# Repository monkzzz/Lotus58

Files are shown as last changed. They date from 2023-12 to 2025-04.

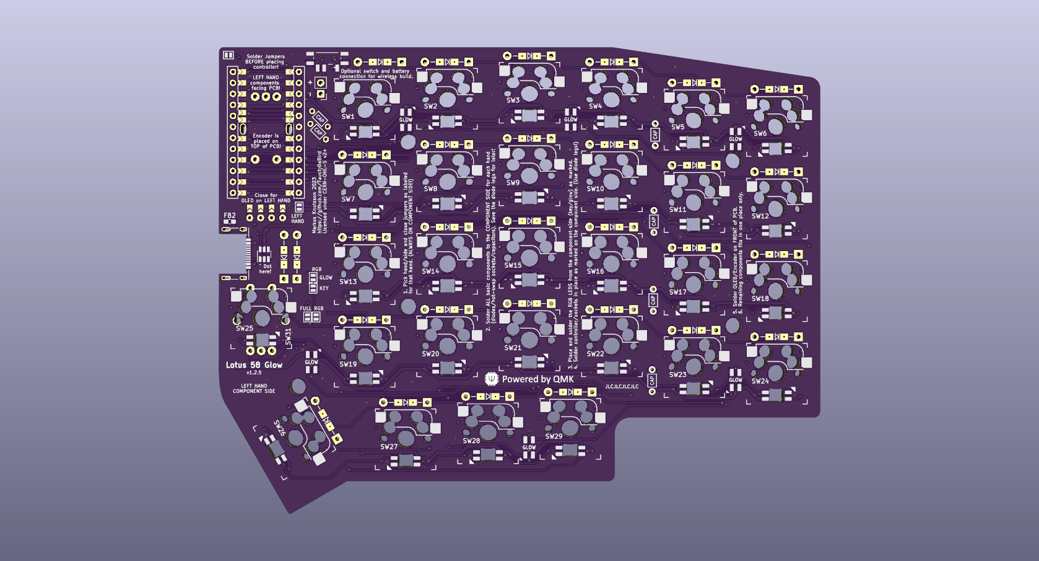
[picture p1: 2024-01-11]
images/Lotus58_Glow_130.png

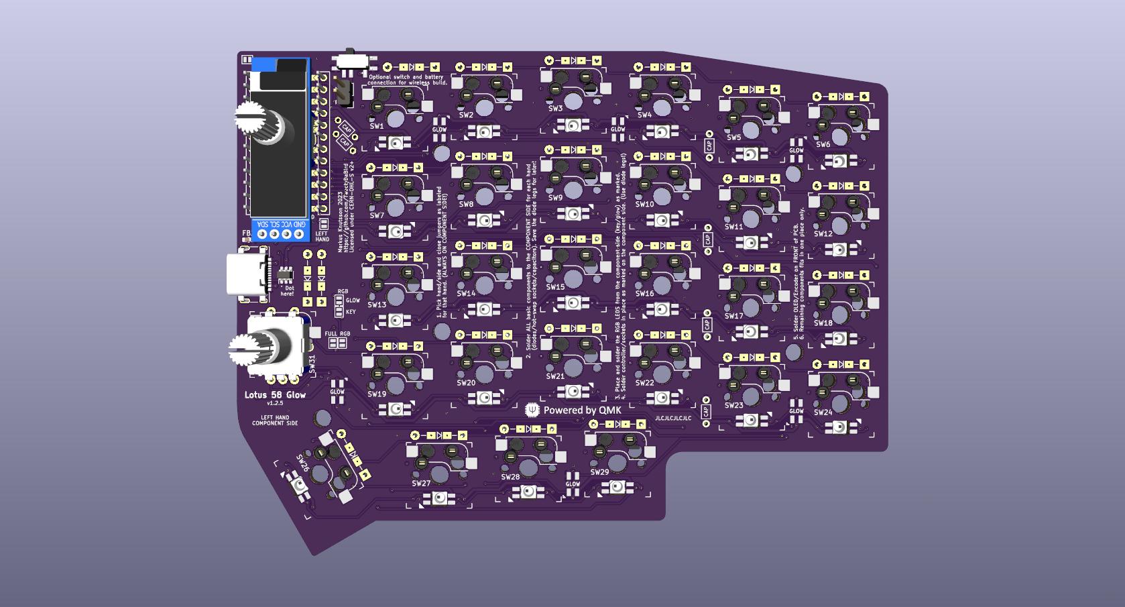
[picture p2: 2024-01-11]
images/Lotus58_Glow_130_LH_comp.jpg

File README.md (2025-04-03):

### Notice! Project files in the development branches are NOT intended for public use in production of PCB's, may or may not be tested and may change or be removed without notice! 
If you order PCB's from these, YOU have the sole responsibility for how these turn out!!! 

**Please use the Gerber files for producing PCB's, found under the header 'Releases' instead (Look here >>).** 

Also please note the difference between a 'Pre-release' (partially/fully untested, basically what I order a prototype PCB from to test) and a full actual 'Release' which is fully tested, built and ready to be used to produce PCB's.

# Lotus 58 Glow - Classic
#### Lotus 58 Classic is the wired designs of the Lotus keyboard. Wireless with BLE and 2.4Ghz dongled wireless reside in other repositories.

Starting with simple tweaks to the Lily58 Glow before ordering a set of PCB's it quickly spiraled out of control, and I ended up with what wasn't quite a Lily58 anymore, and although very similar in layout, it is no longer compatible with plate and case design. 

Because of this, it was renamed Lotus58, referencing another flower much like the lily in the name Lily58.

Lotus 58 Glow
(photo from reddit by u/bduzik)

## General Specifications

- Layout very similar to the original Lily58 family
- Per key RGB and RGB underglow
- Kaihl Hot-swap sockets for MX compatible switches
- Can be used as a standalone Gamepad for either hand
- Optional 0.91" OLED Screens and rotary encoders (one each per side)
- All components through-hole and easily soldered for beginners (SMD option for diodes)
- Designed with a sandwich-style plate/case as part of the design

## Layout variations

- Optional plate layout with OLED screen (Encoder can be placed on upper thumb key position)
- Optional plate layout with rotary encoder (Removes OLED screen for that side)  
- Optional plate layout with no hole for OLED or upper encoder (Encoder can be placed on upper thumb key position)

Layout variations Layout Variations

## 3D-printed Cases
**There are a couple of 'official' commissioned designs for 3D printed cases for the Lotus 58 Glow, available in a separate Git [here](https://github.com/TweetyDaBird/Lotus-Cases).** 

And you can find several more made by users using Google, and/or by joining the Discord channel and chatting to the builders/designers and users.

## Things to note when ordering PCB's
### Finding the Gerber files
If you are not aiming at modifying things, don't look for the gerber files in the folders, pretty please!</BR>
And please don't open yet another issue about it! </BR>
The gerber files are where they belong, zipped up in releases, look under that header for the version you want.

### Tips & Tricks
- Most PCB manufacturers have a MOQ of 5 PCB's, meaning you end up with 2½ keyboards when finished.
- The recommended PCB thickness is 1.6 mm, both for the main PCB and plates to allow the keyswitches to grip the plate and lock in place securely.

If ordering from [JLCPCB](https://www.jlcpcb.com) the plate Gerber files include a reference putting the added serial etc on a breakaway part for a clean look with minimal cost, if using another manufacturer it's possible they have additional fee's for removing the extra text, or you should consider plotting the Gerber files yourself with the correct reference for your manufacturer. Otherwise use the standard settings from JLPCB.

## Build guide
**Some basic build instructions are in the [WIKI](https://github.com/TweetyDaBird/Lotus-58-Classic/wiki), and I really try to keep these updated.** But please keep in mind that whenever these instructions conflict with information on the PCB silkscreen, the silkscreen is and always will be the correct source of information! It's always updated with the version, and the most current information for the PCB version in question. 

**The intent has always been that the keyboard should be able to be fully built with some very basic soldering skills and the instructions on the silkscreen.**

### Discord for further build help and discussions!

<a href="https://discord.gg/G6QzcJQUnm">Discuss on Discord</a>

## Buy a kit!
I sell complete kits, making it easy to build your keyboard, and it also supports prototypes for new wacky ones. 



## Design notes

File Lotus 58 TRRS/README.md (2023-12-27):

# Lotus 58 Glow

Starting with simple tweaks to the Lily58 Glow before ordering a set of PCB's it quickly spiraled out of control, and I ended up with what wasn't quite a Lily58 anymore, and although very similar in layout, it is no longer compatible with plate and case design. 

Because of this, it was renamed Lotus58, referencing another flower much like the lily in the name Lily58.

Lotus 58 Glow
(photo from reddit by u/bduzik)

## TRRS link version - Lotus 58 Classic

This is the original branch of the Lotus 58 Glow design, using the TRRS link. A lot of features have been added along the way for the newer versions.

## General Specifications

- Layout very similar to the original Lily58 family
- Per key RGB and RGB underglow
- Kaihl Hot-swap sockets for MX compatible switches
- Can be used as a standalone Gamepad for either hand
- Optional 0.91" OLED Screens and rotary encoders (one each per side)
- All components through-hole and easily soldered for beginners (SMD option for diodes)
- Designed with a sandwich-style plate/case as part of the design

## Layout variations

- Optional plate layout with OLED screen (Encoder can be placed on upper thumb key position)
- Optional plate layout with rotary encoder (Removes OLED screen for that side)  
- Optional plate layout with no hole for OLED or upper encoder (Encoder can be placed on upper thumb key position)

Layout variations Layout Variations

## Things to note when ordering PCB's
### Finding the Gerber files
If you are not aiming at modifying things, don't look for the gerber files in the folders, pretty please!</BR>
And please don't open yet another issue about it! </BR>
The gerber files are where they belong, zipped up in releases, look under that header for the version you want.

### Tips & Tricks
- Most PCB manufacturers have a MOQ of 5 PCB's, meaning you end up with 2½ keyboards when finished.
- The recommended PCB thickness is 1.6 mm, both for the main PCB and plates to allow the keyswitches to grip the plate and lock in place securely.

If ordering from [JLCPCB](https://www.jlcpcb.com) the plate Gerber files include a reference putting the added serial etc on a breakaway part for a clean look with minimal cost, if using another manufacturer it's possible they have additional fee's for removing the extra text, or you should consider plotting the Gerber files yourself with the correct reference for your manufacturer. Otherwise use the standard settings from JLPCB.

## Buy a kit!
I sell complete kits, making it easy to build your keyboard, and it also supports prototypes for new wacky ones. 



## Discord for build help and discussions!

<a href="https://discord.gg/G6QzcJQUnm">Discuss on Discord</a>

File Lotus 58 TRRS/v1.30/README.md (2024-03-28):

# Lotus 58 v1.28

Starting with simple tweaks to the Lily58 Glow before ordering a set of PCB's it quickly spiraled out of control, and I ended up with what wasn't quite a Lily58 anymore, and although very similar in layout, it is no longer compatible with plate and case design. 

Because of this, it was renamed Lotus58, referencing another flower much like the lily in the name Lily58.

# Lotus 58 Glow

Lotus 58 Glow
(photo from reddit by u/bduzik)

Fully backwards compatible physically identical outline for plates and identical firmware. Updates required to 3D cases for the reset/power switch.

# Parts needed

| Name of part | Qty. | Optional | Remarks | Aliexpress |
| --- | ---- | --- | --- | --- |
| PCB | 2 | X | 1,6 mm thick | X |
| Top plate | 2 | X | Optional layouts for OLED or encoder in top position. | X |
| Bottom plate | 2 | X | X | X |
| Kailh hotswap socket | 56-58 | X | Qty. depends on layout. | [link](https://www.aliexpress.com/item/-/4001051840976.html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) |
| Diodes 1N4841 (TH) or 1N4148W (SMD) | 56-58 | X | Qty. depends on layout. TH recommended for beginners. | [link(TH)](https://www.aliexpress.com/item/HOT-SELL-100-PCS-1N4148-DO-35-IN4148-Silicon-Switching-Diode-FREE-SHIPPMENT/32660088529.html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) or [link(SMD)](https://www.aliexpress.ru/item/-/1005002059571417.html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) |
| Capacitors 100 nF | 0-4 | ✔ | Qty. depends on layout. 2 needed for each encoder installed. | [link](https://www.aliexpress.com/item/-/32971478818.html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) |
| Resistor 4.7 kOhm | 0-4 | ✔ | Qty. depends on layout. 2 needed for each OLED installed. | [link](https://www.aliexpress.com/item/-/32847047012.html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) |
| 0.91" OLED Display | 0-2 | ✔ | Qty. depends on layout. | [link](https://www.aliexpress.com/item/-/4001028384269.html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) |
| TRRS jack PJ-320A | 2 | X | X | [link](https://www.aliexpress.com/item/-/4000114275750.html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) |
| M2 * 12 mm standoff | 10 | X | Rounded, max 3.7 mm in diameter | [link](https://www.aliexpress.com/item/-/32863484622.html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) |
| M2 * 4 mm screw | 20 | X | 4-8 mm length fits, low profile hex head recommended | [link](https://www.aliexpress.com/item/-/32966917947.html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) |
| TRRS cable | 1 | X | Needs to be 4 poles, more common 3 poles cable creates a shortcircuit | [link](https://www.aliexpress.com/item/32905903526.html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,searchweb201602_,searchweb201603_) |
| Silicon pads | 10 | X | X | [link](https://www.aliexpress.com/item/-/32912066603.html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) |
| Pro Micro | 2 | X | Can be built with various ProMicro clones as well as Elite C (Or nice!nano for a wireless keyboard) | [link](https://www.aliexpress.com/item/-/32849563958.html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) |
| MillMax low profile sockets | 1 | ✔ | Purchased as 1x64 pin and split | [link](https://eu.mouser.com/ProductDetail/575-641503)|
| Rotary Encoder | 0-2 | ✔ | Qty. depends on layout. | [link](https://www.aliexpress.com/item/10000056483250.html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,searchweb201602_,searchweb201603_) |
| Rotary Encoder Knob | 0-2 | ✔ | One needed for each encoder. Clearance for max 24 mm diameter, pick halfshaft or spline according to encoder choice.  | [link](https://www.aliexpress.com/item/10000056483250.html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,searchweb201602_,searchweb201603_) |
| SK6803/SK6805/SK6812 mini-E (3535) | 12/58 (70) | ✔ | Qty. depends on layout and if used as per-key or underglow (or both). Mini E are winged for easier soldering. | [link](https://www.aliexpress.com/item/4000475685852.html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,searchweb201602_,searchweb201603_) |
| SRV05-4	ESD | 0-2 | ✔ | Optional but recommended for ESD protection. | [link](https://www.lcsc.com/product-detail/Electrostatic-and-Surge-Protection-TVS-ESD_TECH-PUBLIC-SRV05-4_C558418.html)|
| MSK12C02 Slide switch | 0-2 | ✔ | Optional RGB select or Power switch | [link](https://www.lcsc.com/product-detail/Slide-Switches_SHOU-HAN-MSK12C02_C431540.html)|

## Things to note when ordering PCB's
### Finding the Gerber files
If you are not aiming at modifying things, don't look for the gerber files in the folders, pretty please!</BR>
And please don't open yet another issue about it! </BR>
The gerber files are where they belong, zipped up in releases, look under that header for the version you want.

### Tips & Tricks
- Most PCB manufacturers have a MOQ of 5 PCB's, meaning you end up with 2½ keyboards when finished.
- The recommended PCB thickness is 1.6 mm, both for the main PCB and plates to allow the keyswitches to grip the plate and lock in place securely.

If ordering from [JLPCB](https://www.jlpcb.com) the plate Gerber files include a reference putting the added serial etc on a breakaway part for a clean look with minimal cost, if using another manufacturer it's possible they have additional fee's for removing the extra text, or you should consider plotting the Gerber files yourself with the correct reference for your manufacturer. Otherwise use the standard settings from JLPCB.

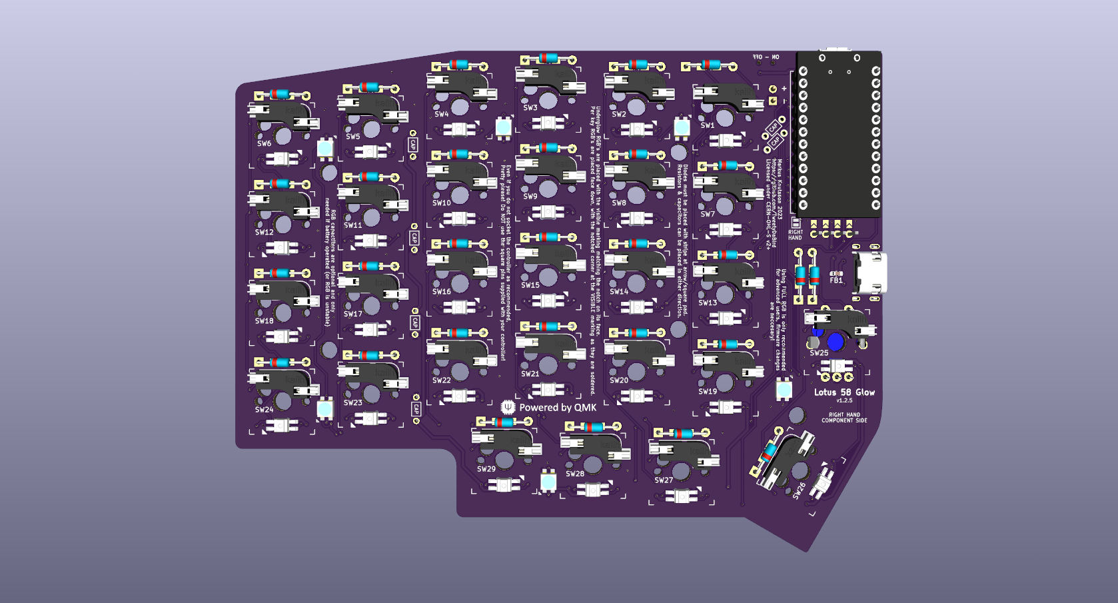
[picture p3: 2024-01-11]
images/Lotus58_Glow_130_RH_comp.png

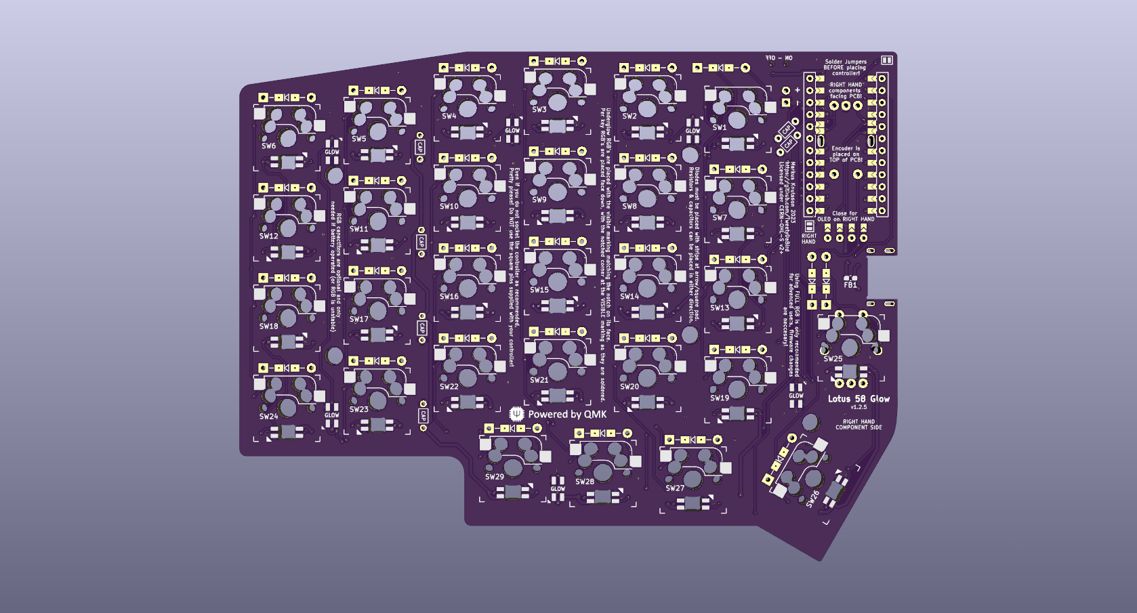
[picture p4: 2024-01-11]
images/Lotus58_Glow_130_RH.png

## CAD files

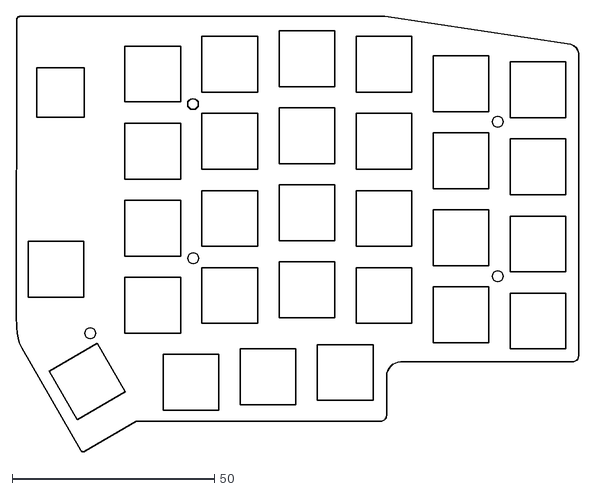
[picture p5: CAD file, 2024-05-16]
Lotus Plate/DXF/Laser_Cut_Top_Plate_ENC.dxf
139.1 x 107.7

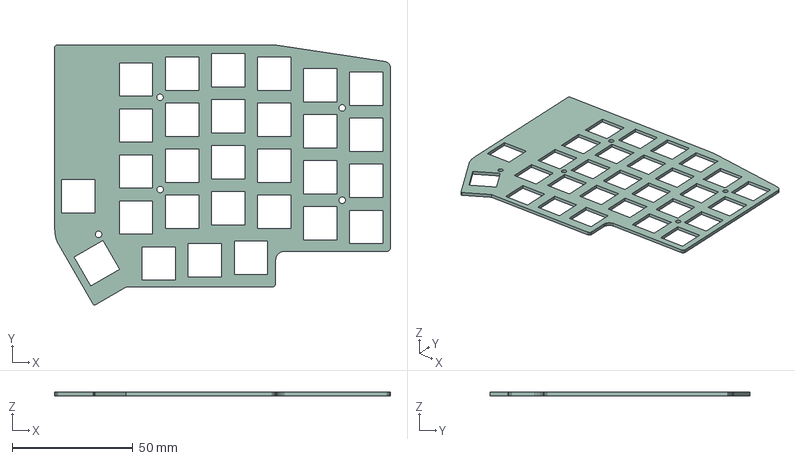
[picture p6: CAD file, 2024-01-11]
Lotus Plate/Step file/FR4_Top_Plate_BLANK.step
139.1 x 107.7 x 1.60 mm

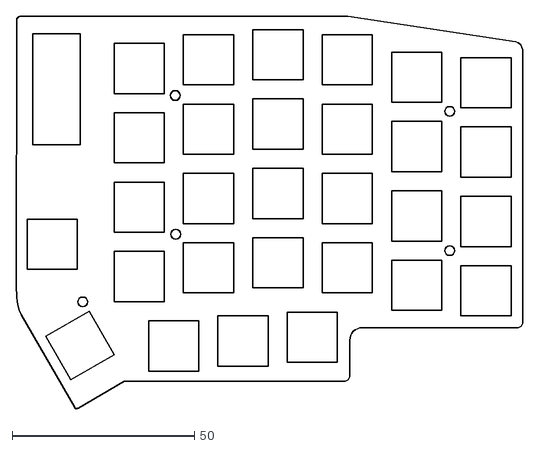
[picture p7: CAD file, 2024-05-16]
Lotus Plate/DXF/Laser_Cut_Top_Plate_OLED.dxf
139.1 x 107.7

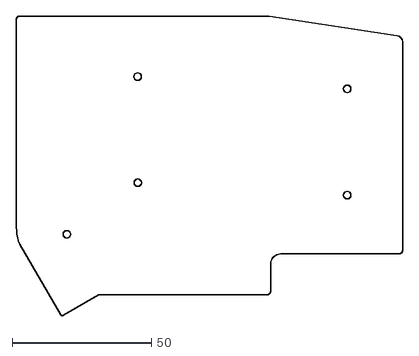
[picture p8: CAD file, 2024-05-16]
Lotus Plate/DXF/Laser_Cut_Bottom_Plate.dxf
139.1 x 107.7

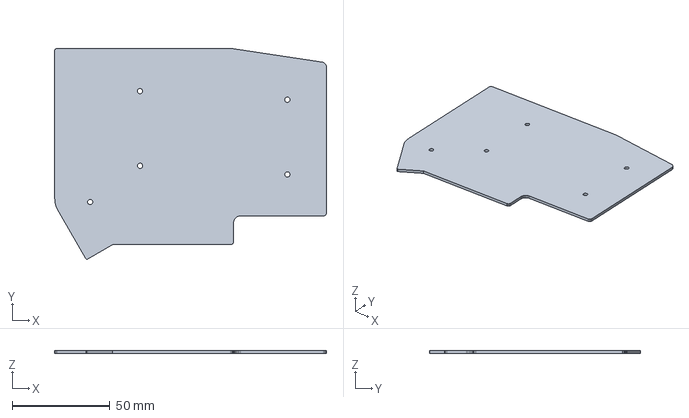
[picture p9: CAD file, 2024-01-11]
Lotus Plate/Step file/FR4_Bottom_Plate.step
139.1 x 107.7 x 1.60 mm

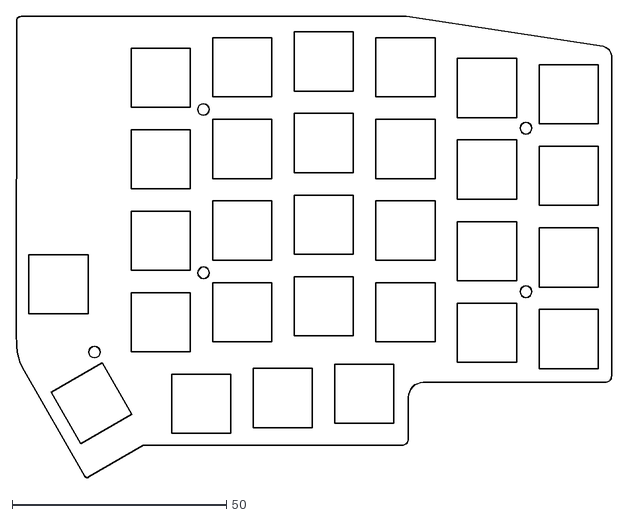
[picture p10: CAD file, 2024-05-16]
Lotus Plate/DXF/Laser_Cut_Top_Plate_Blank.dxf
139.1 x 107.7

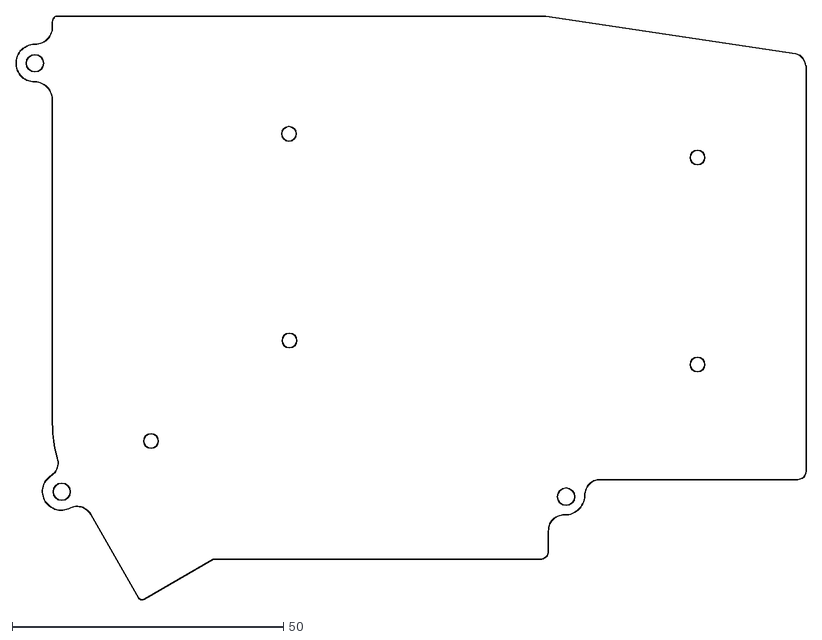
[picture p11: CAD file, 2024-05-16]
Lotus Plate/DXF/Laser_Cut_Bottom_Plate_TENT.dxf
145.7 x 107.7

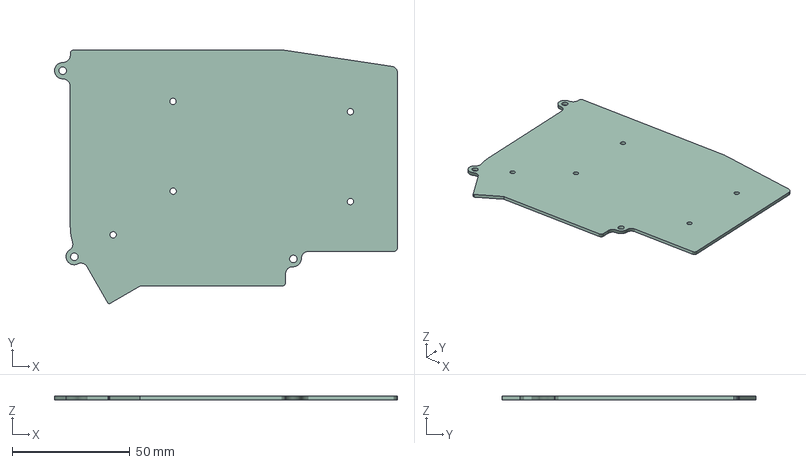
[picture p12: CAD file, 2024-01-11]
Lotus Plate/Step file/FR4_Bottom_Plate_TENT.step
145.7 x 107.7 x 1.60 mm

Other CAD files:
Lotus Plate/Step file/FR4_Top_Plate_OLED.step
Lotus Plate/Step file/FR4_Top_Plate_ENC.step

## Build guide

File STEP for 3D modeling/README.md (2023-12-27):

### STEP files used for 3D modeling cases etc.
All relevant components are modeled and present on both sides of the PCB, as they are not always 100% symmetrical (placement depends on traces etc). Keep in mind that the modeling should as standard use the component placed on the bottom side of the PCB for each respective hand.

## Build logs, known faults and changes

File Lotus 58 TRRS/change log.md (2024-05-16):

Change Log Lotus 58 Glow TRRS/Classic

- v1.00 - Initial release
   - This verison unfortunately had various RGB issues. Used through hole mounted SK6812 mini RGB's for both per-key and glow.
- v1.11 - Intermediary release
  - RGB issues fixed, improved silkscreen for easier building.
- v1.23 - Second release
  - Greatly improved design, per-key moved to SK6812 mini-e winged RGB, and glow remains as surface mounted SK6812 mini.
  - Added support for battery connector and power switch for wireless builds.
- v1.24 - Intermediary release
   - Added Silkscreen build instructions
  - Added TRRS ESD protection
  - Removed i2c resistors
  - Repositioned reset for easier access
  - Minor cleanup of routing and silkscreen
- v1.26 - Third Release
  - Brings TRRS variant to feature parity with USB C variant by moving ALL RGB to SK6812 mini-e.
  - All RGB can be soldered, and either glow or key can be selected to be active (drawing power)
  - Switch positions are the same as USB-C so reset and power switch can now be on both sides of PCB (easier 3D printing)
  - Better footprints, so easier to solder.
  - Since the TRRS version already have a power switch, the RGB is an internal switch, placed where you need to disassemble, alternatively hard soldered jumpers.
- v1.27 - Intermediary release
  - Improved Silkscreen/build instructions on PCB
- v1.28 - Fourth release
  - Possible to select the function of the external slide switch, setting it as a power switch for wireless builds, or to select RGB for a wired build

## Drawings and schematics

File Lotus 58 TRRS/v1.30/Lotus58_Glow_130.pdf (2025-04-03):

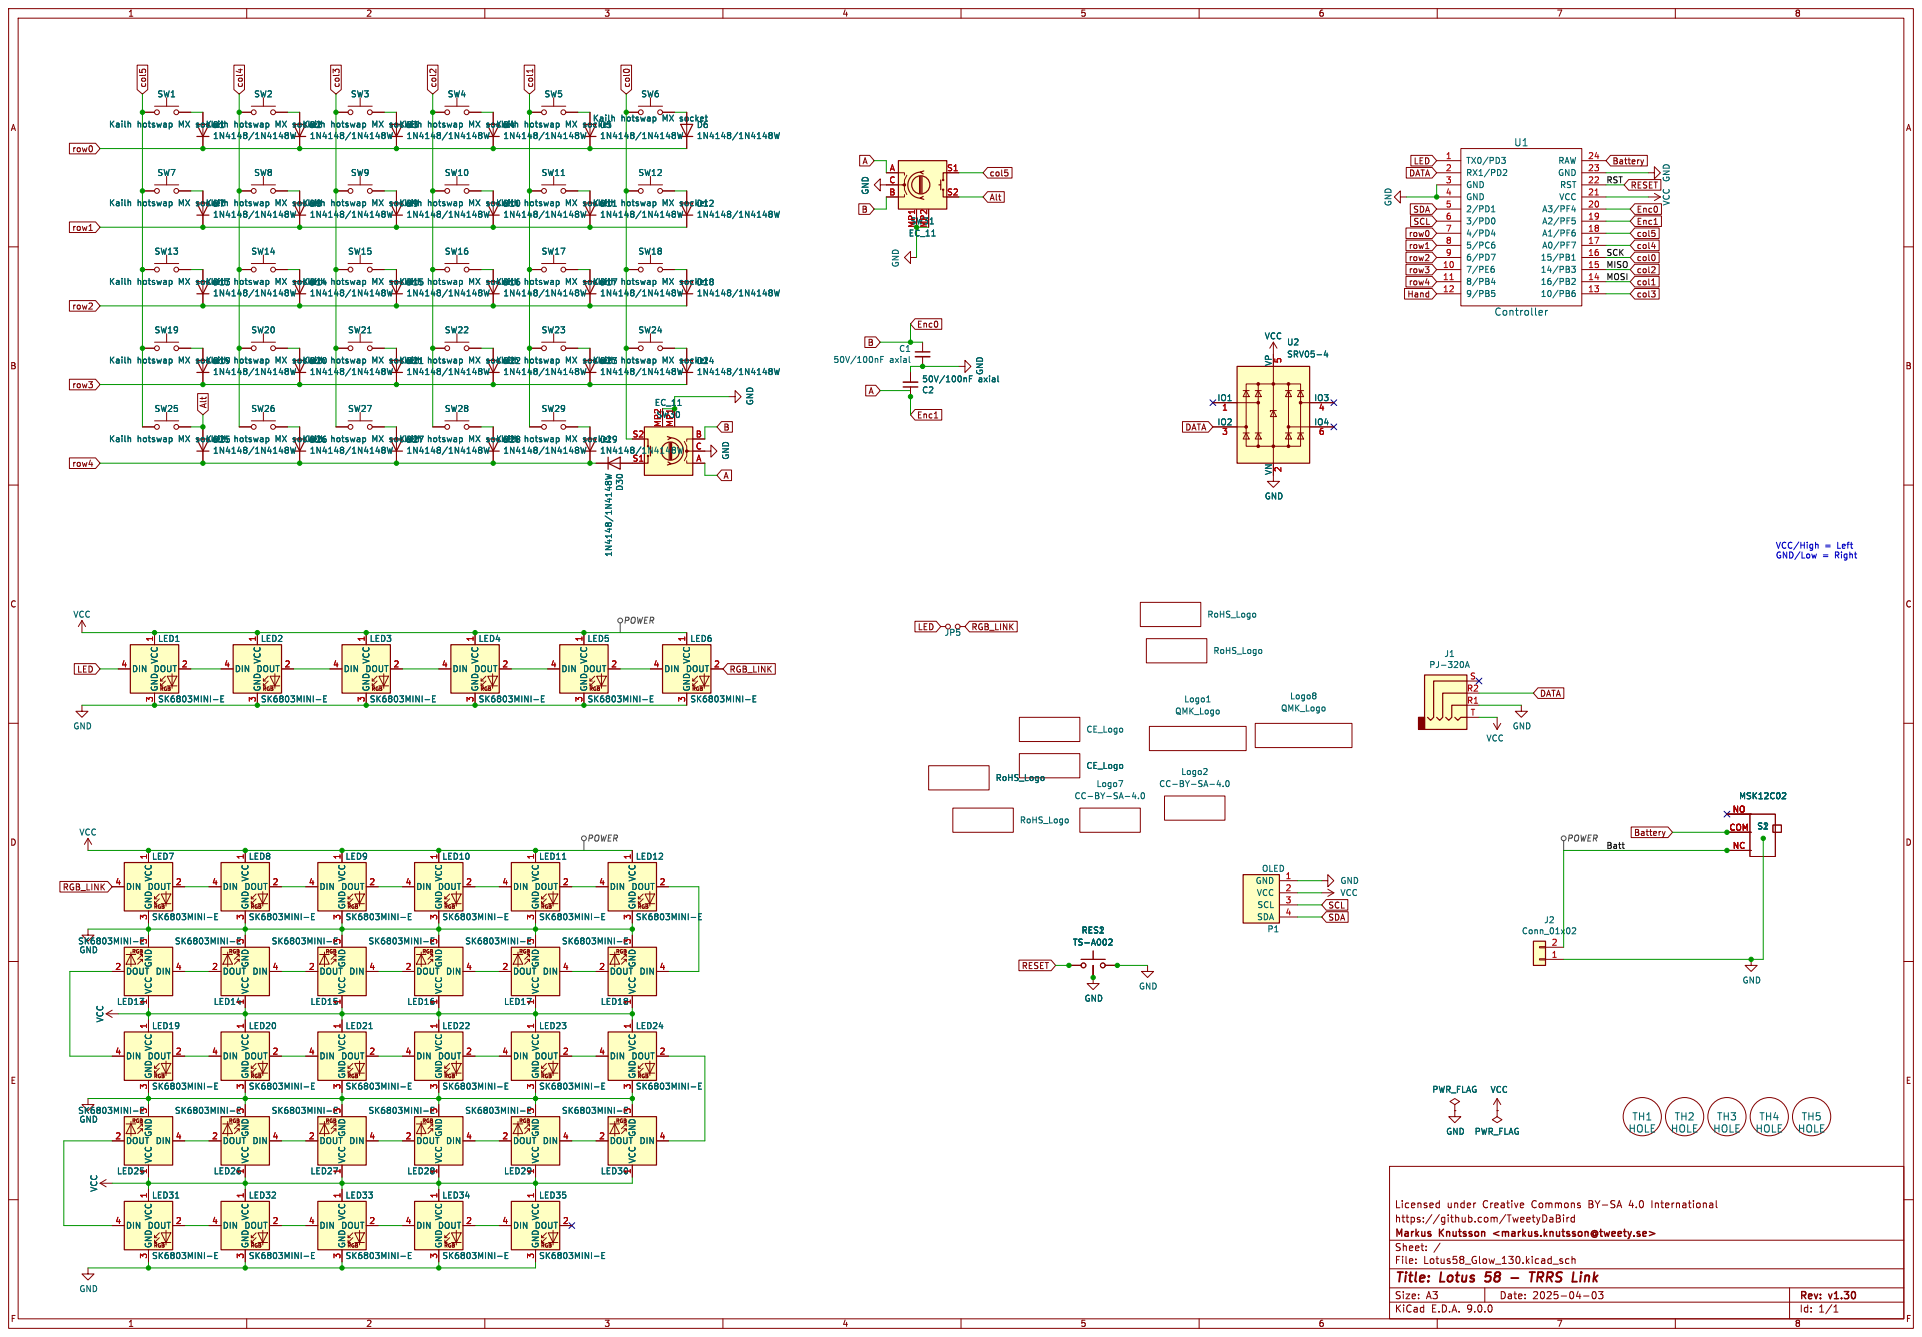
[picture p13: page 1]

SW2 Kailh hotswap MX socket D26

SW1 Kailh hotswap MX socket

SW3 Kailh D2 hotswap MX socket 1N4148/1N4148W

SW4 Kailh hotswap MX socket SW9 Kailh D8 hotswap MX socket 1N4148/1N4148W

SW4 Kailh hotswap MX socket

SW5 Kailh hotswap MX socket

SW6 Kailh hotswap MX socket SW12 Kailh hotswap MX socket D5

SW8 Kailh D7 hotswap MX socket 1N4148/1N4148W

SW9 Kailh D8 hotswap MX socket 1N4148/1N4148W

SW10 Kailh hotswap MX socket

SW10 Kailh D9 hotswap MX socket 1N4148/1N4148W

SW11 Kailh hotswap MX socket SW17 Kailh D16 hotswap MX socket 1N4148/1N4148W

SW18 Kailh hotswap MX socket D11

SW15 Kailh hotswap MX socket SW21 Kailh hotswap MX socket SW26 Kailh D25 hotswap MX socket 1N4148/1N4148W

SW16 Kailh hotswap MX socket

SW16 Kailh hotswap MX socket SW22 Kailh hotswap MX socket D15

SW20 Kailh hotswap MX socket D13

SW22 Kailh hotswap MX socket D15

SW24 Kailh hotswap MX socket D17

SW25 Kailh hotswap MX socket SW19 Kailh hotswap MX socket D19
SW25 Kailh hotswap MX socket VCC

VCC GND GND GND

https://github.com/TweetyDaBird

Id: 1/1 Title: Lotus 58 - TRRS Link

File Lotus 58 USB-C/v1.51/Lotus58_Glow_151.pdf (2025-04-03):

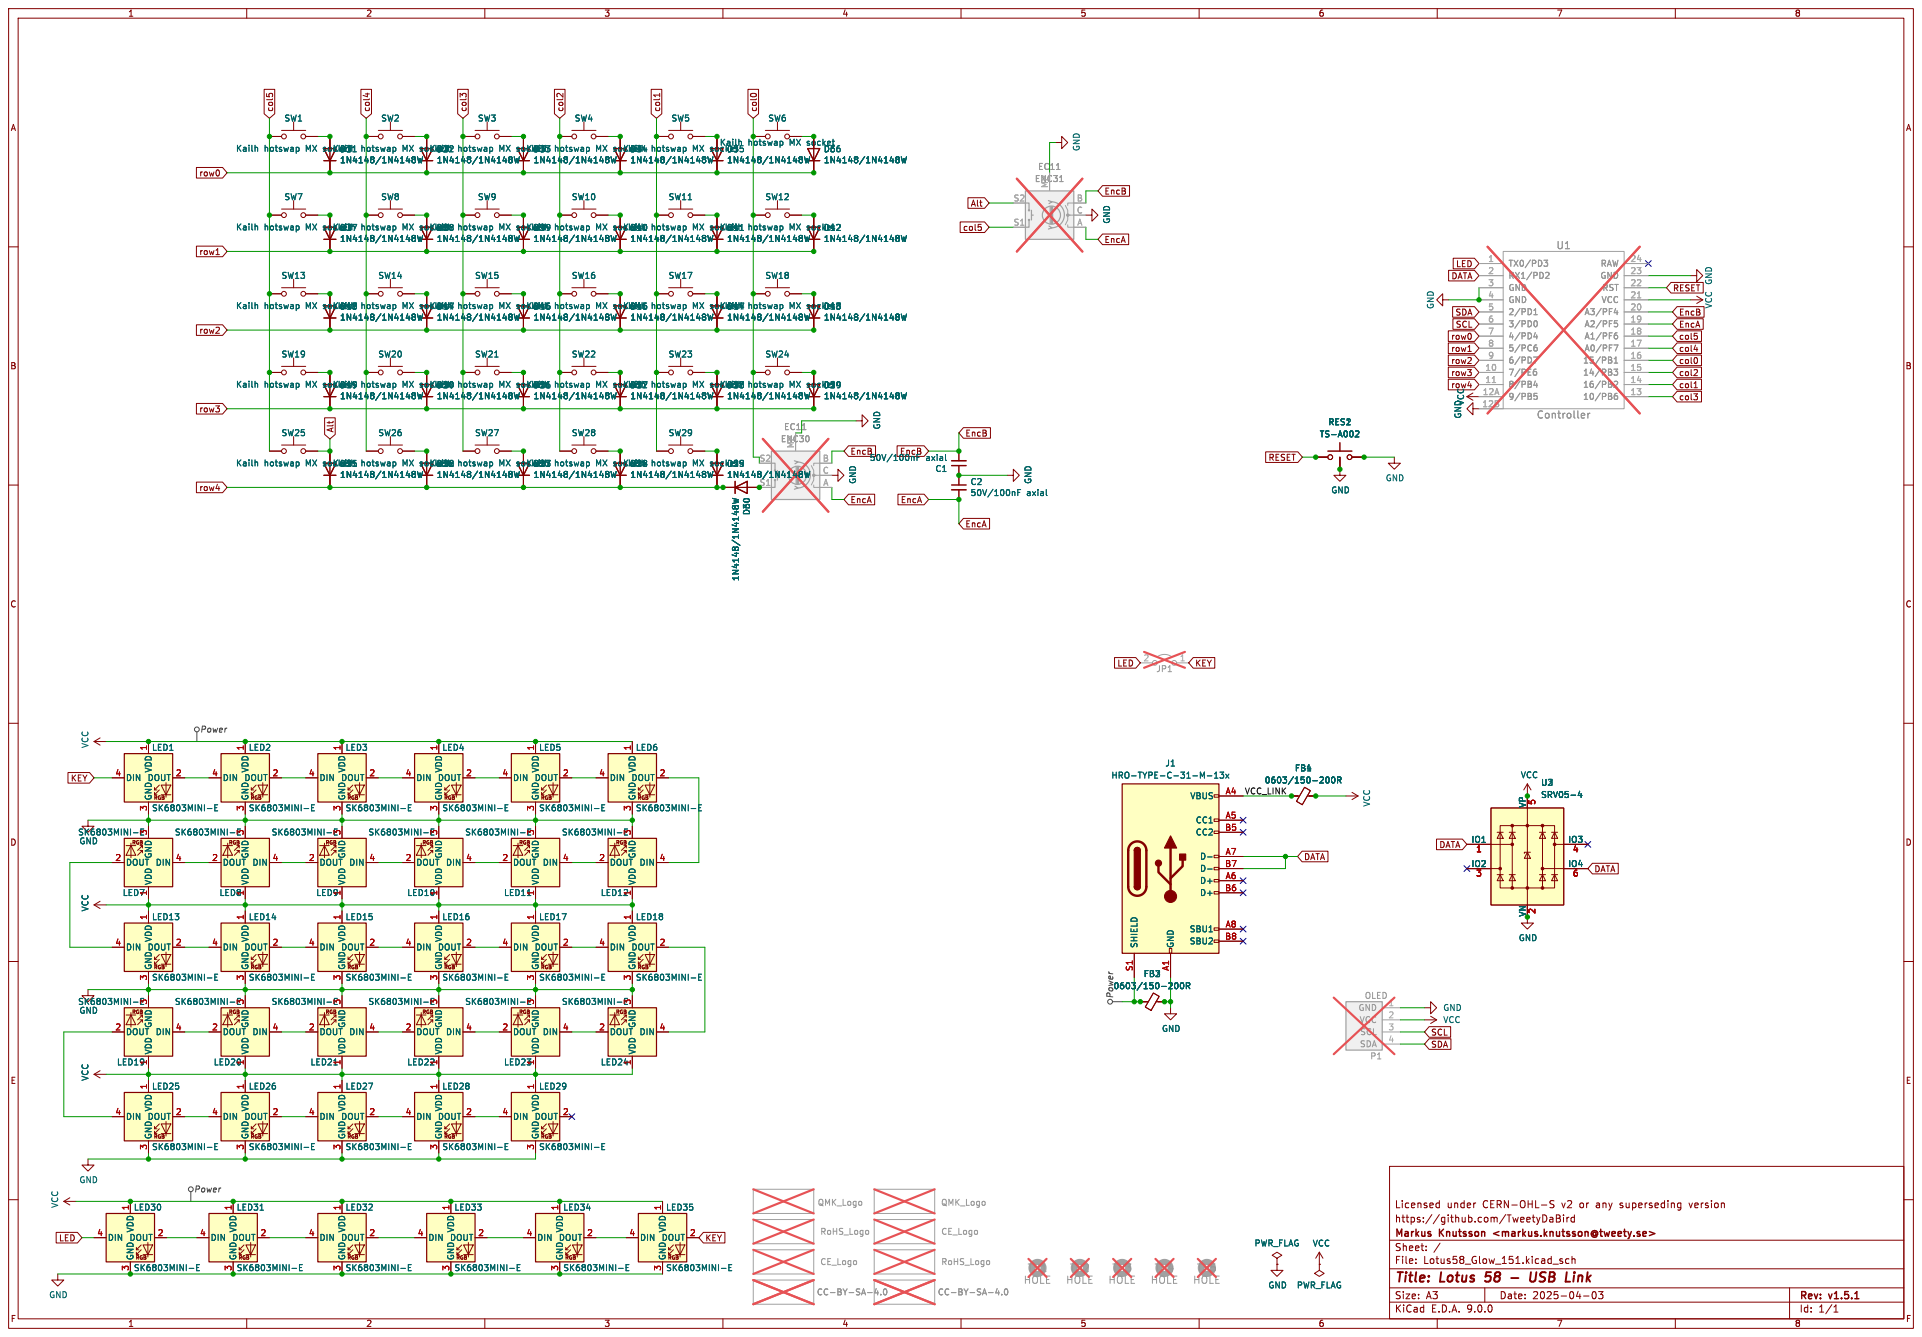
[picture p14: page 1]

SW5 Kailh D34 hotswap MX socket 1N4148/1N4148W VCC

SW7 Kailh hotswap MX socket SW1 Kailh hotswap MX socket

SW7 Kailh hotswap MX socket SW1 Kailh hotswap MX socket D1

SW3 Kailh D32 hotswap MX socket 1N4148/1N4148W

SW11 Kailh hotswap MX socket SW5 Kailh D34 hotswap MX socket 1N4148/1N4148W

D35 SW8 Kailh D7 hotswap MX socket 1N4148/1N4148W

SW9 Kailh D38 hotswap MX socket 1N4148/1N4148W

SW10 Kailh D9 hotswap MX socket 1N4148/1N4148W

SW11 Kailh hotswap MX socket

SW15 Kailh hotswap MX socket D8

SW17 Kailh hotswap MX socket D10

D48 SW13 Kailh hotswap MX socket SW19 Kailh hotswap MX socket D25

SW14 Kailh hotswap MX socket SW20 Kailh hotswap MX socket

SW16 Kailh hotswap MX socket

SW18 Kailh D44 hotswap MX socket 1N4148/1N4148W

SW24 Kailh hotswap MX socket D18

SW19 Kailh hotswap MX socket

SW21 Kailh hotswap MX socket

SW21 Kailh D20 hotswap MX socket 1N4148/1N4148W

SW22 Kailh D56 hotswap MX socket 1N4148/1N4148W

SW23 Kailh D22 hotswap MX socket 1N4148/1N4148W

SW25 Kailh hotswap MX socket

SW26 Kailh D51 hotswap MX socket 1N4148/1N4148W

SW27 Kailh D26 hotswap MX socket 1N4148/1N4148W

SW28 Kailh D53 hotswap MX socket 1N4148/1N4148W

SW29 Kailh D28 hotswap MX socket 1N4148/1N4148W

3 DOUT 2 CC-BY-SA-4.0

https://github.com/TweetyDaBird

Id: 1/1 Title: Lotus 58 - USB Link

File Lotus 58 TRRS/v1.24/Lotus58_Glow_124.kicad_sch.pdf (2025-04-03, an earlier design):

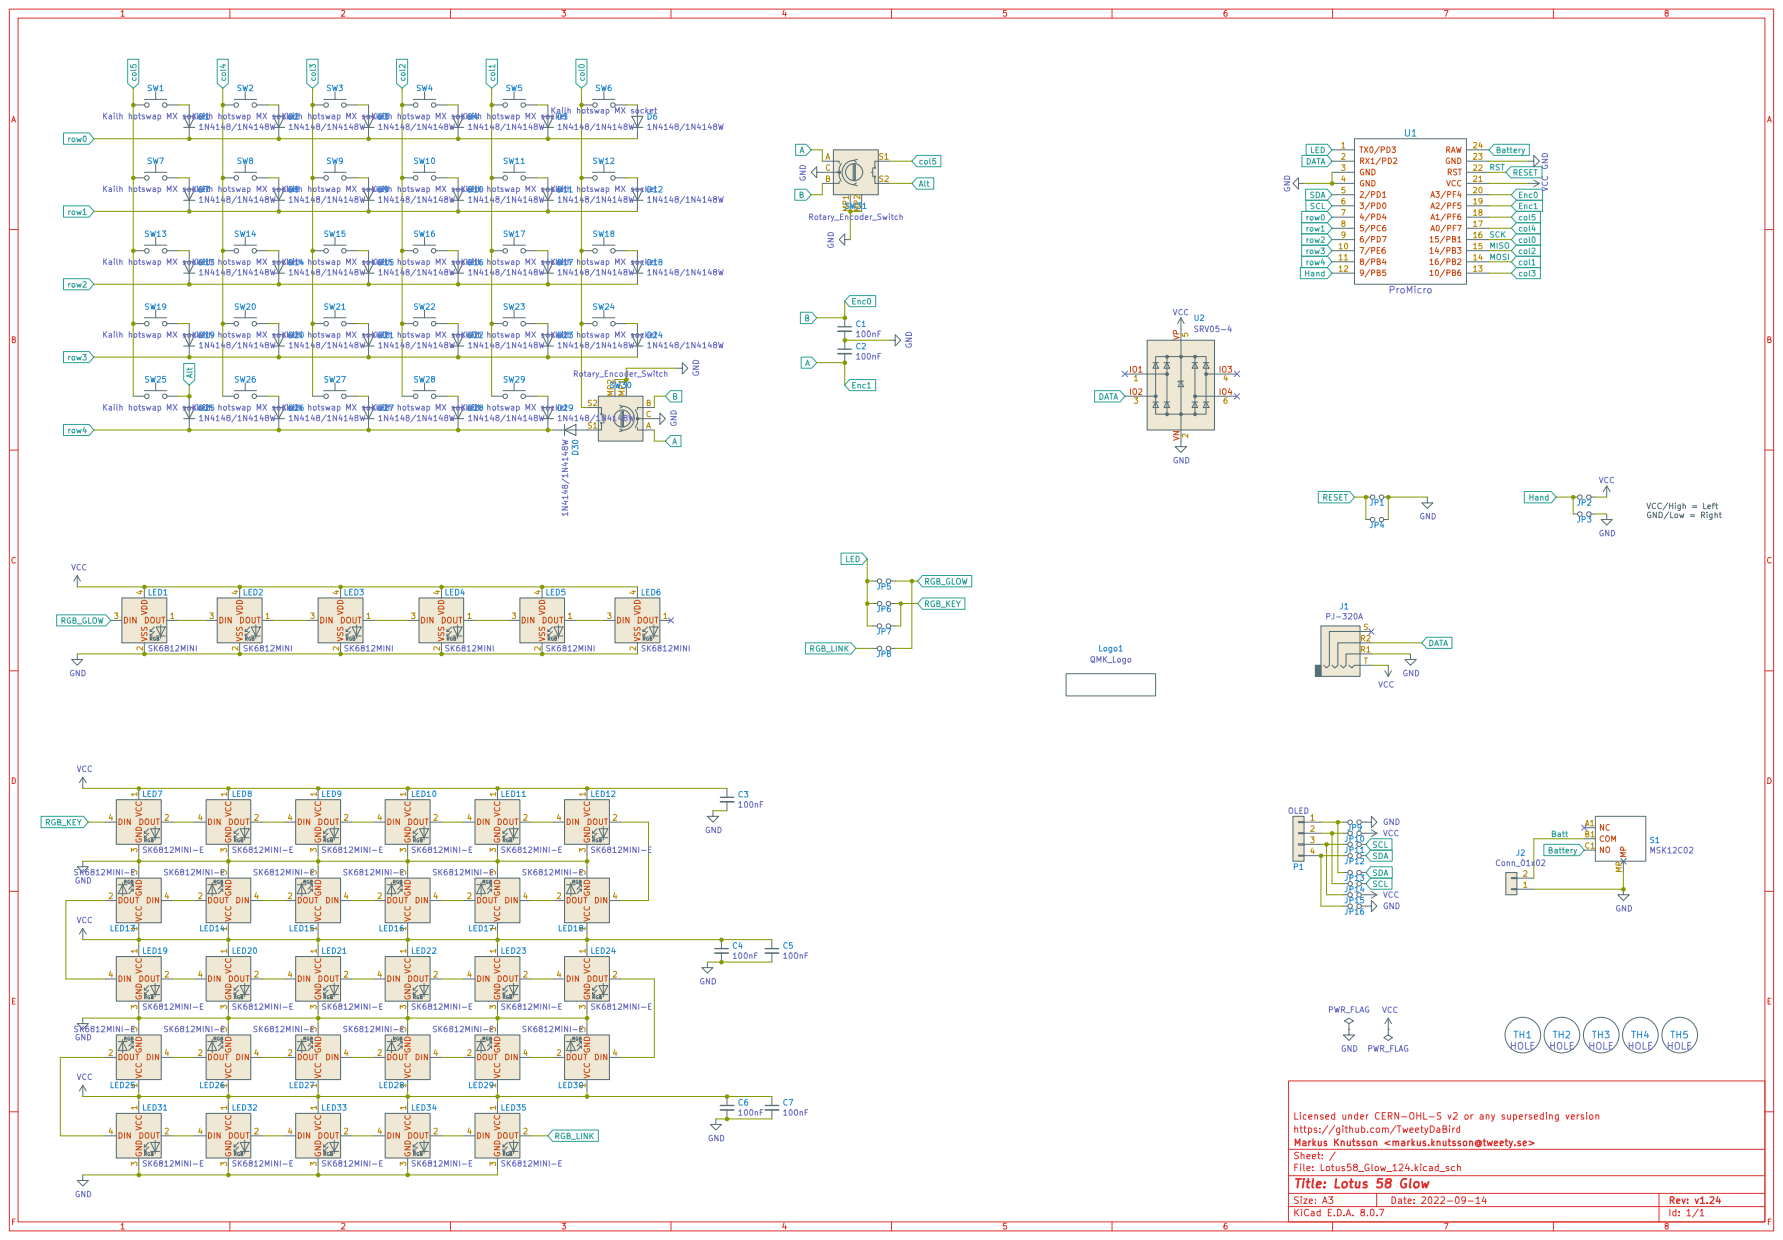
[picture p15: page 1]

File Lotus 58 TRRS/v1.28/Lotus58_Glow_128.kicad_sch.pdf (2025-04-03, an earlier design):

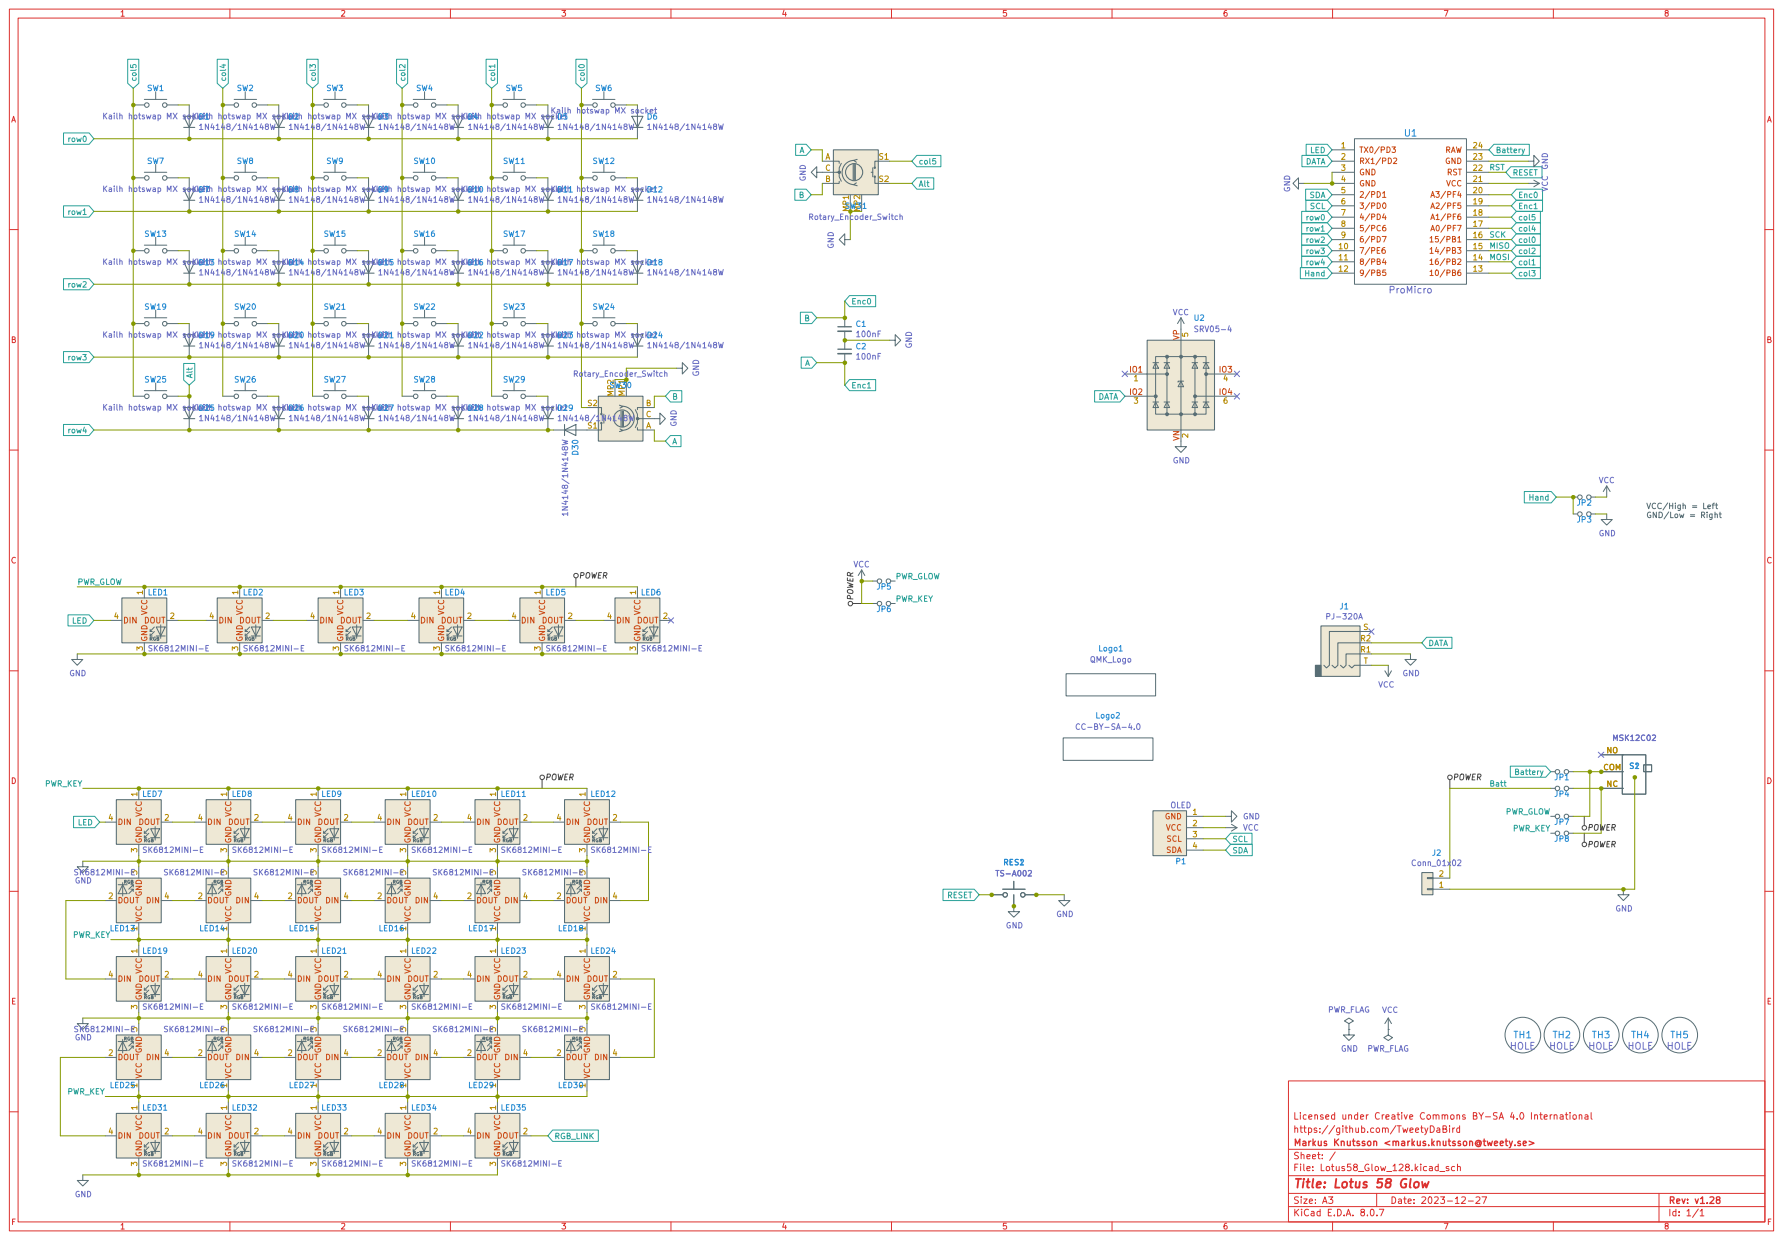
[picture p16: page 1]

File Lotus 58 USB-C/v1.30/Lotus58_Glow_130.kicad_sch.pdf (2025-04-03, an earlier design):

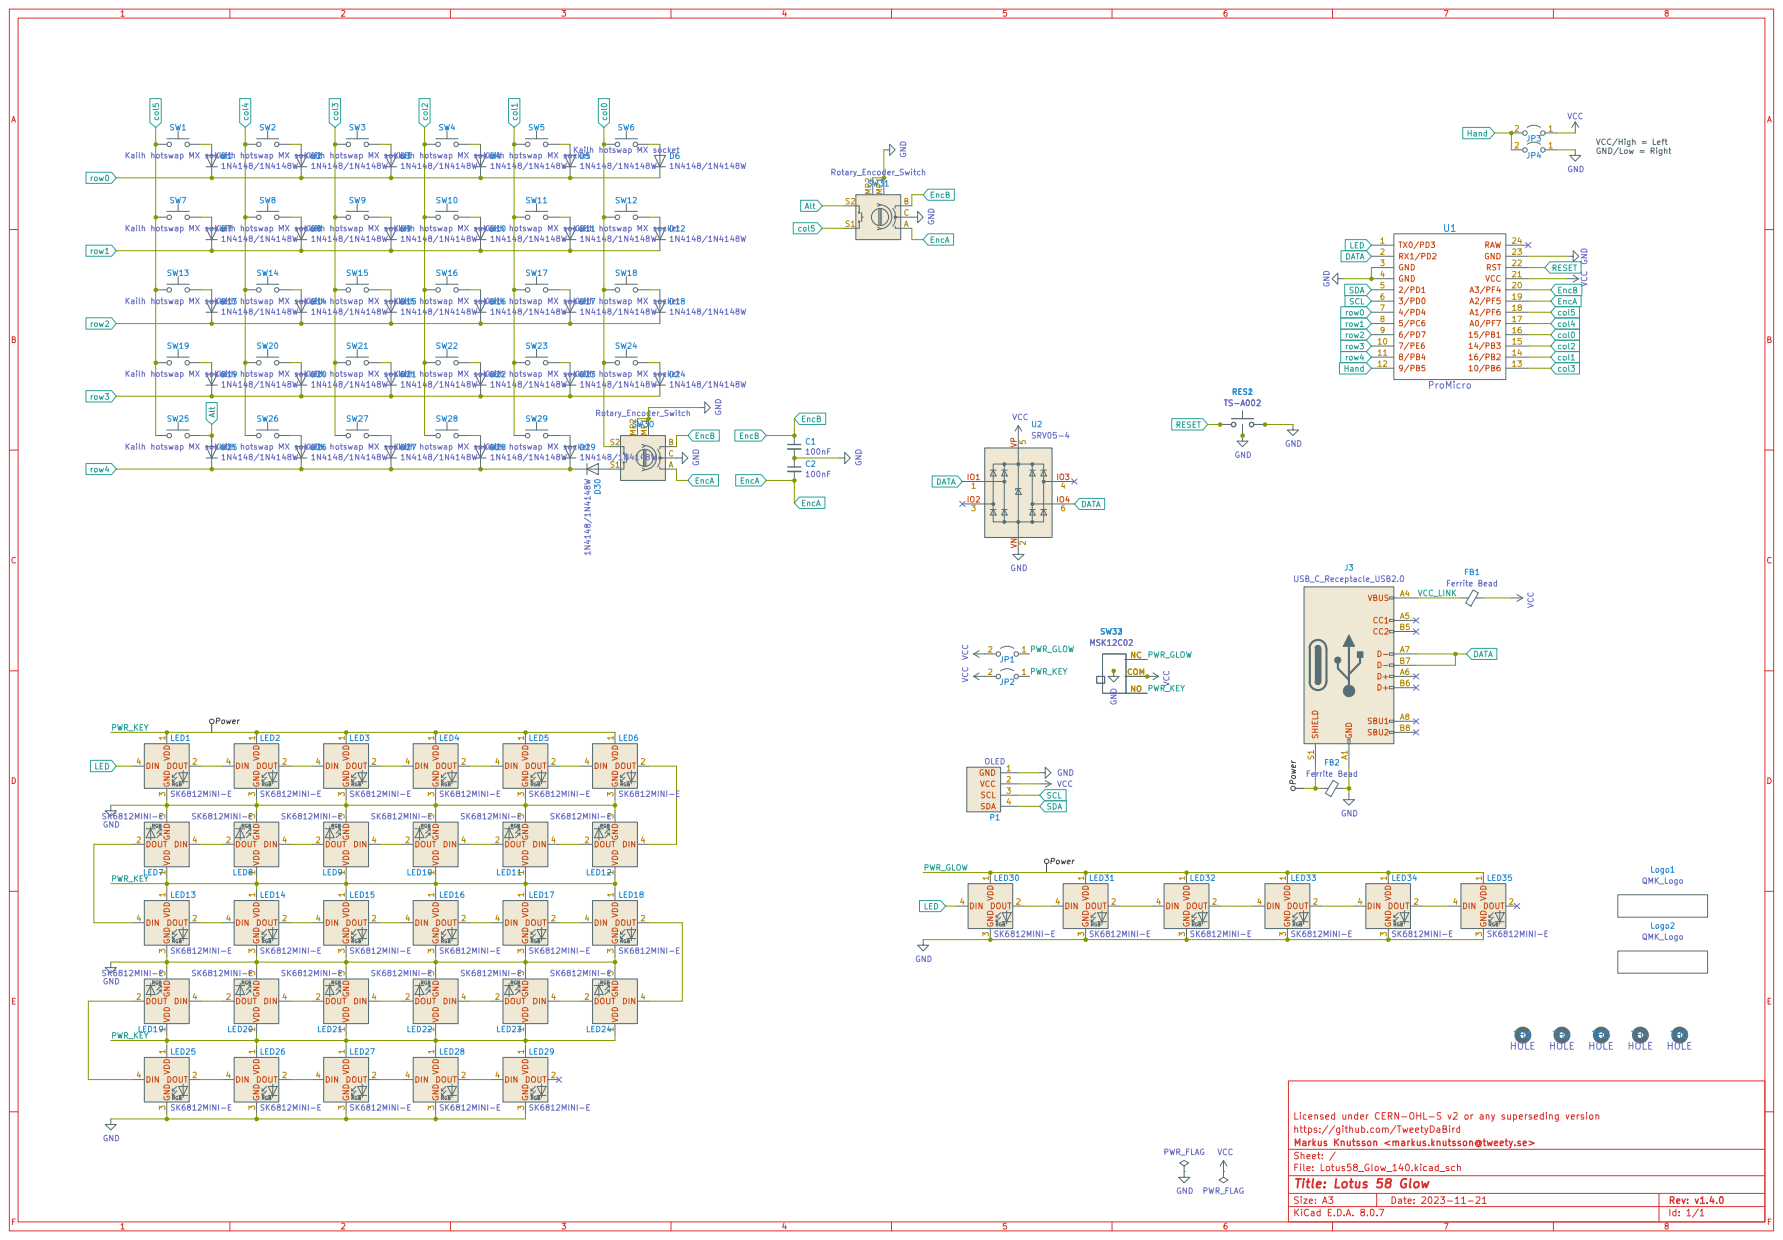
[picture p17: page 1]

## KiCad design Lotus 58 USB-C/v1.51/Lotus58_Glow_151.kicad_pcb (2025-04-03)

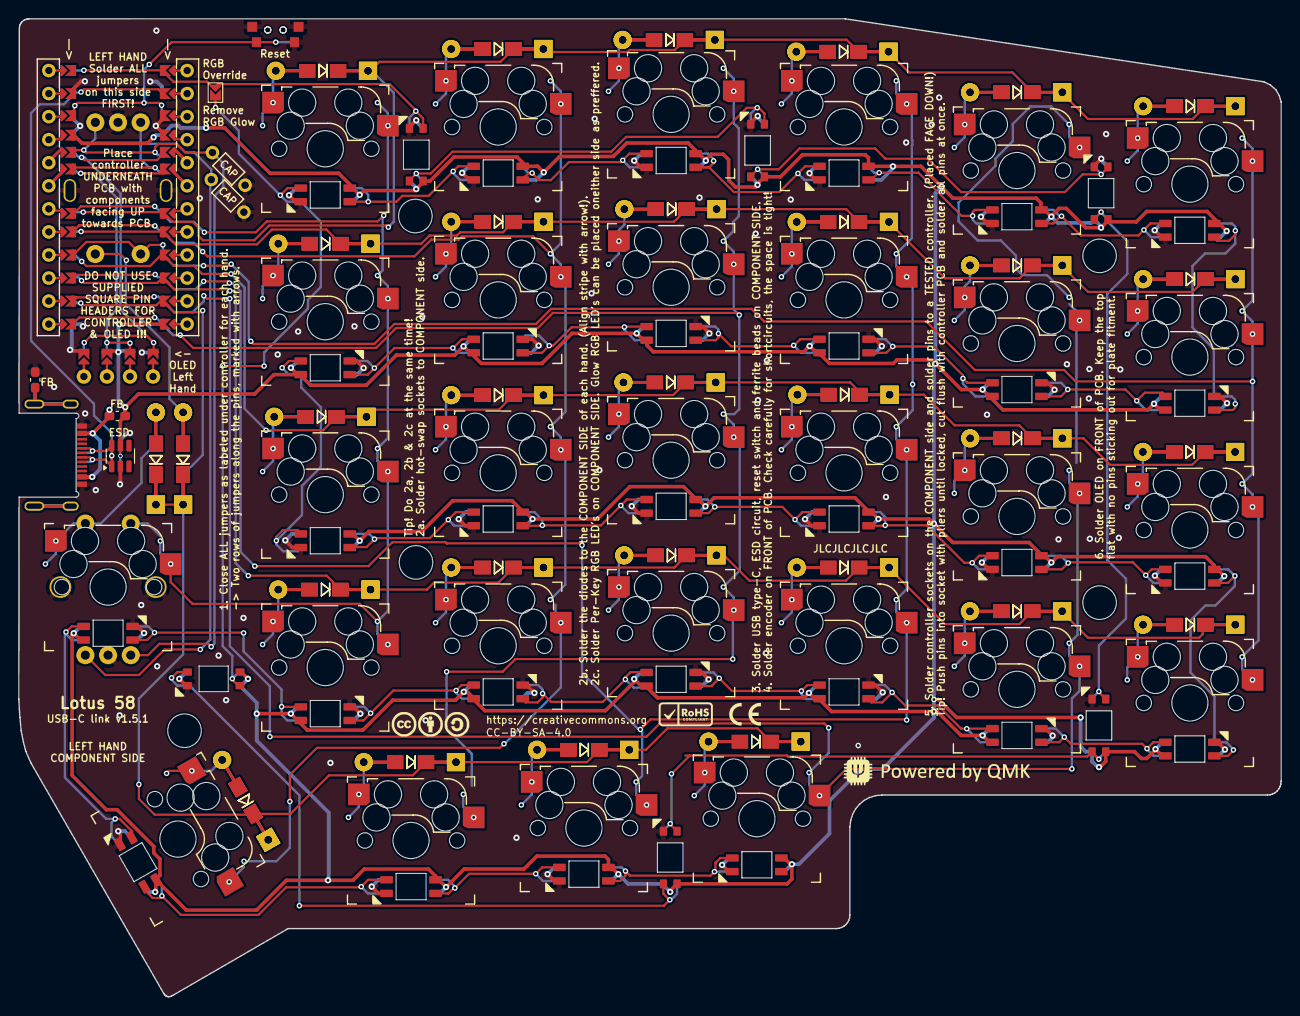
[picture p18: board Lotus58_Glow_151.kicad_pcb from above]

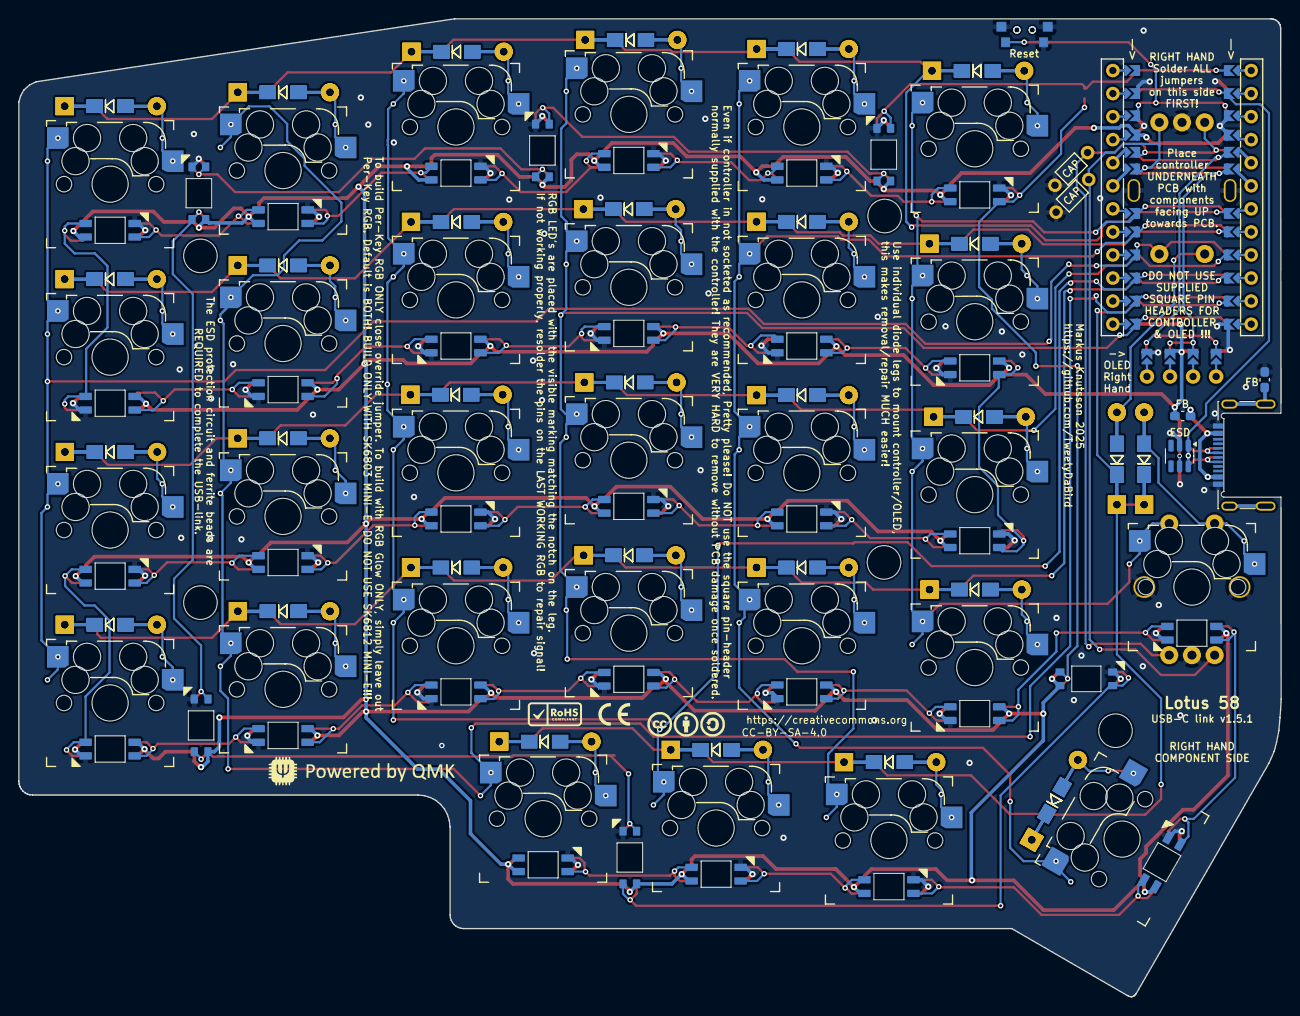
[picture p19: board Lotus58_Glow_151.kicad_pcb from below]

Board: 2 copper layers, 139.1 x 107.7 mm, 151 parts (40 on the bottom side), 86 nets.

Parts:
C1, C2: 50V/100nF axial; RESISTOR_Reversible
D1, D2, D3, D4, D5, D6, D7, D8, D9, D10, D11, D12, D13, D14, D15, D16, D17, D18, D19, D20, D21, D22, D23, D24, D25, D26, D27, D28, D29, D30, D31, D32, D33, D34, D35, D36, D37, D38, D39, D40, D41, D42, D43, D44, D45, D46, D47, D48, D49, D50, D51, D52, D53, D54, D55, D56, D57, D58, D59, D60: 1N4148/1N4148W; Diode_DO35_SOD123
ENC30: EC11; Encoder_Alps_EC11E_Small
ENC31: EC11; Encoder_Alps_EC11E_Small_onkey
FB1, FB2, FB3, FB4: 0603/150-200R; C_0603_1608Metric_Pad1.08x0.95mm_HandSolder
J1: HRO-TYPE-C-31-M-13x; Molex-216990_GCT-USB45xx_HRO-TYPE-C-31-M-13x-PiMicro_1_DOUB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
JP1: LEFT; Jumper_min_v2
LED1, LED2, LED3, LED4, LED5, LED6, LED7, LED8, LED9, LED10, LED11, LED12, LED13, LED14, LED15, LED16, LED17, LED18, LED19, LED20, LED21, LED22, LED23, LED24, LED25, LED26, LED27, LED28, LED29: SK6803MINI-E; MX_SK6812MINI-E_REVERSIBLE
LED30, LED31, LED32, LED33, LED34, LED35: SK6803MINI-E; MX_SK6812MINI-E_REVERSIBLE_special_v2
Logo1, Logo2: QMK_Logo; qmk logo
Logo4, Logo6: CE_Logo; CE
Logo7, Logo8: CC-BY-SA-4.0; CC_BY_SA_40_line
P1: OLED; SSD1306-0.91-OLED-4pin-128x32 doublesided
RES1, RES2: TS-A002; YTS-A002
SW1, SW2, SW3, SW4, SW5, SW6, SW7, SW8, SW9, SW10, SW11, SW12, SW13, SW14, SW15, SW16, SW17, SW18, SW19, SW20, SW21, SW22, SW23, SW24, SW25, SW26, SW27, SW28, SW29: Kailh hotswap MX socket; SW_MX_HotSwap_Reversible
TH1, TH2, TH3, TH4, TH5: HOLE; Spacer PCB hole
U1: Controller; ProMicro_jumpers_V3
U2, U3: SRV05-4; SOT-23-6

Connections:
/VCC_LINK: FB1.1, FB4.1, J1.A4 (VBUS), J1.A9 (VBUS), J1.B4 (VBUS), J1.B9 (VBUS)
Alt: D25.2 (A), D51.2 (A), ENC31.S2, SW25.1
DATA: J1.A7 (D-), J1.B7 (D-), U1.2 (RX1/PD2), U2.1 (IO1), U2.6 (IO4), U3.1 (IO1), U3.6 (IO4)
EncA: C2.2, ENC30.A, ENC31.A, U1.19 (A2/PF5)
EncB: C1.2, ENC30.B, ENC31.B, U1.20 (A3/PF4)
GND: C1.1, C2.1, ENC30.C, ENC30.MP (GND), ENC31.C, ENC31.MP (GND), FB2.2, FB3.2, J1.A1 (GND), J1.A12 (GND), J1.B1 (GND), J1.B12 (GND), LED1.3 (GND), LED2.3 (GND), LED3.3 (GND), LED4.3 (GND), LED5.3 (GND), LED6.3 (GND), LED7.3 (GND), LED8.3 (GND), LED9.3 (GND), LED10.3 (GND), LED11.3 (GND), LED12.3 (GND), LED13.3 (GND), LED14.3 (GND), LED15.3 (GND), LED16.3 (GND), LED17.3 (GND), LED18.3 (GND), LED19.3 (GND), LED20.3 (GND), LED21.3 (GND), LED22.3 (GND), LED23.3 (GND), LED24.3 (GND), LED25.3 (GND), LED26.3 (GND), LED27.3 (GND), LED28.3 (GND), LED29.3 (GND), LED30.3 (GND), LED31.3 (GND), LED32.3 (GND), LED33.3 (GND), LED34.3 (GND), LED35.3 (GND), P1.1 (GND), RES1.2, RES1.3, RES2.2, RES2.3, U1.3 (GND), U1.4 (GND), U1.12B, U1.23 (GND), U2.2 (VN), U3.2 (VN)
KEY: JP1.1 (A), LED1.4 (DIN), LED35.2 (DOUT)
LED: JP1.2 (B), LED30.4 (DIN), U1.1 (TX0/PD3)
unnamed: D1.2 (A), D31.2 (A), SW1.1
unnamed: D2.2 (A), D32.2 (A), SW2.1
unnamed: D3.2 (A), D33.2 (A), SW3.1
unnamed: D10.2 (A), D40.2 (A), SW10.1
unnamed: D11.2 (A), D41.2 (A), SW11.1
unnamed: D12.2 (A), D42.2 (A), SW12.1
unnamed: D13.2 (A), D48.2 (A), SW13.1
unnamed: D14.2 (A), D47.2 (A), SW14.1
unnamed: D15.2 (A), D46.2 (A), SW15.1
unnamed: D16.2 (A), D45.2 (A), SW16.1
unnamed: D17.2 (A), D44.2 (A), SW17.1
unnamed: D18.2 (A), D43.2 (A), SW18.1
unnamed: D19.2 (A), D49.2 (A), SW19.1
unnamed: D20.2 (A), D50.2 (A), SW20.1
unnamed: D21.2 (A), D56.2 (A), SW21.1
unnamed: D22.2 (A), D57.2 (A), SW22.1
unnamed: D23.2 (A), D58.2 (A), SW23.1
unnamed: D24.2 (A), D59.2 (A), SW24.1
unnamed: D26.2 (A), D52.2 (A), SW26.1
unnamed: D27.2 (A), D53.2 (A), SW27.1
unnamed: D28.2 (A), D54.2 (A), SW28.1
unnamed: D29.2 (A), D55.2 (A), SW29.1
unnamed: D30.2 (A), D60.2 (A), ENC30.S1
unnamed: D4.2 (A), D34.2 (A), SW4.1
unnamed: D5.2 (A), D35.2 (A), SW5.1
unnamed: D6.2 (A), D36.2 (A), SW6.1
unnamed: D7.2 (A), D37.2 (A), SW7.1
unnamed: D8.2 (A), D38.2 (A), SW8.1
unnamed: D9.2 (A), D39.2 (A), SW9.1
unnamed: FB2.1, FB3.1, J1.S1 (SHIELD)
unnamed: LED1.2 (DOUT), LED2.4 (DIN)
unnamed: LED2.2 (DOUT), LED3.4 (DIN)
unnamed: LED3.2 (DOUT), LED4.4 (DIN)
unnamed: LED4.2 (DOUT), LED5.4 (DIN)
unnamed: LED5.2 (DOUT), LED6.4 (DIN)
unnamed: LED7.4 (DIN), LED8.2 (DOUT)
unnamed: LED8.4 (DIN), LED9.2 (DOUT)
unnamed: LED10.4 (DIN), LED11.2 (DOUT)
unnamed: LED9.4 (DIN), LED10.2 (DOUT)
unnamed: LED11.4 (DIN), LED12.2 (DOUT)
unnamed: LED6.2 (DOUT), LED12.4 (DIN)
unnamed: LED7.2 (DOUT), LED13.4 (DIN)
unnamed: LED13.2 (DOUT), LED14.4 (DIN)
unnamed: LED14.2 (DOUT), LED15.4 (DIN)
unnamed: LED15.2 (DOUT), LED16.4 (DIN)
unnamed: LED16.2 (DOUT), LED17.4 (DIN)
unnamed: LED17.2 (DOUT), LED18.4 (DIN)
unnamed: LED18.2 (DOUT), LED24.4 (DIN)
unnamed: LED19.4 (DIN), LED20.2 (DOUT)
unnamed: LED19.2 (DOUT), LED25.4 (DIN)
unnamed: LED20.4 (DIN), LED21.2 (DOUT)
unnamed: LED21.4 (DIN), LED22.2 (DOUT)
unnamed: LED22.4 (DIN), LED23.2 (DOUT)
unnamed: LED23.4 (DIN), LED24.2 (DOUT)
unnamed: LED25.2 (DOUT), LED26.4 (DIN)
unnamed: LED26.2 (DOUT), LED27.4 (DIN)
unnamed: LED27.2 (DOUT), LED28.4 (DIN)
unnamed: LED28.2 (DOUT), LED29.4 (DIN)
unnamed: LED30.2 (DOUT), LED31.4 (DIN)
unnamed: LED31.2 (DOUT), LED32.4 (DIN)
unnamed: LED32.2 (DOUT), LED33.4 (DIN)
unnamed: LED33.2 (DOUT), LED34.4 (DIN)
unnamed: LED34.2 (DOUT), LED35.4 (DIN)
RESET: RES1.1, RES2.1, U1.22 (RST)
SCL: P1.3 (SCL), U1.6 (3/PD0)
SDA: P1.4 (SDA), U1.5 (2/PD1)
VCC: FB1.2, FB4.2, LED1.1 (VDD), LED2.1 (VDD), LED3.1 (VDD), LED4.1 (VDD), LED5.1 (VDD), LED6.1 (VDD), LED7.1 (VDD), LED8.1 (VDD), LED9.1 (VDD), LED10.1 (VDD), LED11.1 (VDD), LED12.1 (VDD), LED13.1 (VDD), LED14.1 (VDD), LED15.1 (VDD), LED16.1 (VDD), LED17.1 (VDD), LED18.1 (VDD), LED19.1 (VDD), LED20.1 (VDD), LED21.1 (VDD), LED22.1 (VDD), LED23.1 (VDD), LED24.1 (VDD), LED25.1 (VDD), LED26.1 (VDD), LED27.1 (VDD), LED28.1 (VDD), LED29.1 (VDD), LED30.1 (VDD), LED31.1 (VDD), LED32.1 (VDD), LED33.1 (VDD), LED34.1 (VDD), LED35.1 (VDD), P1.2 (VCC), U1.12A (9/PB5), U1.21 (VCC), U2.5 (VP), U3.5 (VP)
col0: ENC30.S2, SW6.2, SW12.2, SW18.2, SW24.2, U1.16 (15/PB1)
col1: SW5.2, SW11.2, SW17.2, SW23.2, SW29.2, U1.14 (16/PB2)
col2: SW4.2, SW10.2, SW16.2, SW22.2, SW28.2, U1.15 (14/PB3)
col3: SW3.2, SW9.2, SW15.2, SW21.2, SW27.2, U1.13 (10/PB6)
col4: SW2.2, SW8.2, SW14.2, SW20.2, SW26.2, U1.17 (A0/PF7)
col5: ENC31.S1, SW1.2, SW7.2, SW13.2, SW19.2, SW25.2, U1.18 (A1/PF6)
row0: D1.1 (K), D2.1 (K), D3.1 (K), D4.1 (K), D5.1 (K), D6.1 (K), D31.1 (K), D32.1 (K), D33.1 (K), D34.1 (K), D35.1 (K), D36.1 (K), U1.7 (4/PD4)
row1: D7.1 (K), D8.1 (K), D9.1 (K), D10.1 (K), D11.1 (K), D12.1 (K), D37.1 (K), D38.1 (K), D39.1 (K), D40.1 (K), D41.1 (K), D42.1 (K), U1.8 (5/PC6)
row2: D13.1 (K), D14.1 (K), D15.1 (K), D16.1 (K), D17.1 (K), D18.1 (K), D43.1 (K), D44.1 (K), D45.1 (K), D46.1 (K), D47.1 (K), D48.1 (K), U1.9 (6/PD7)
row3: D19.1 (K), D20.1 (K), D21.1 (K), D22.1 (K), D23.1 (K), D24.1 (K), D49.1 (K), D50.1 (K), D56.1 (K), D57.1 (K), D58.1 (K), D59.1 (K), U1.10 (7/PE6)
row4: D25.1 (K), D26.1 (K), D27.1 (K), D28.1 (K), D29.1 (K), D30.1 (K), D51.1 (K), D52.1 (K), D53.1 (K), D54.1 (K), D55.1 (K), D60.1 (K), U1.11 (8/PB4)

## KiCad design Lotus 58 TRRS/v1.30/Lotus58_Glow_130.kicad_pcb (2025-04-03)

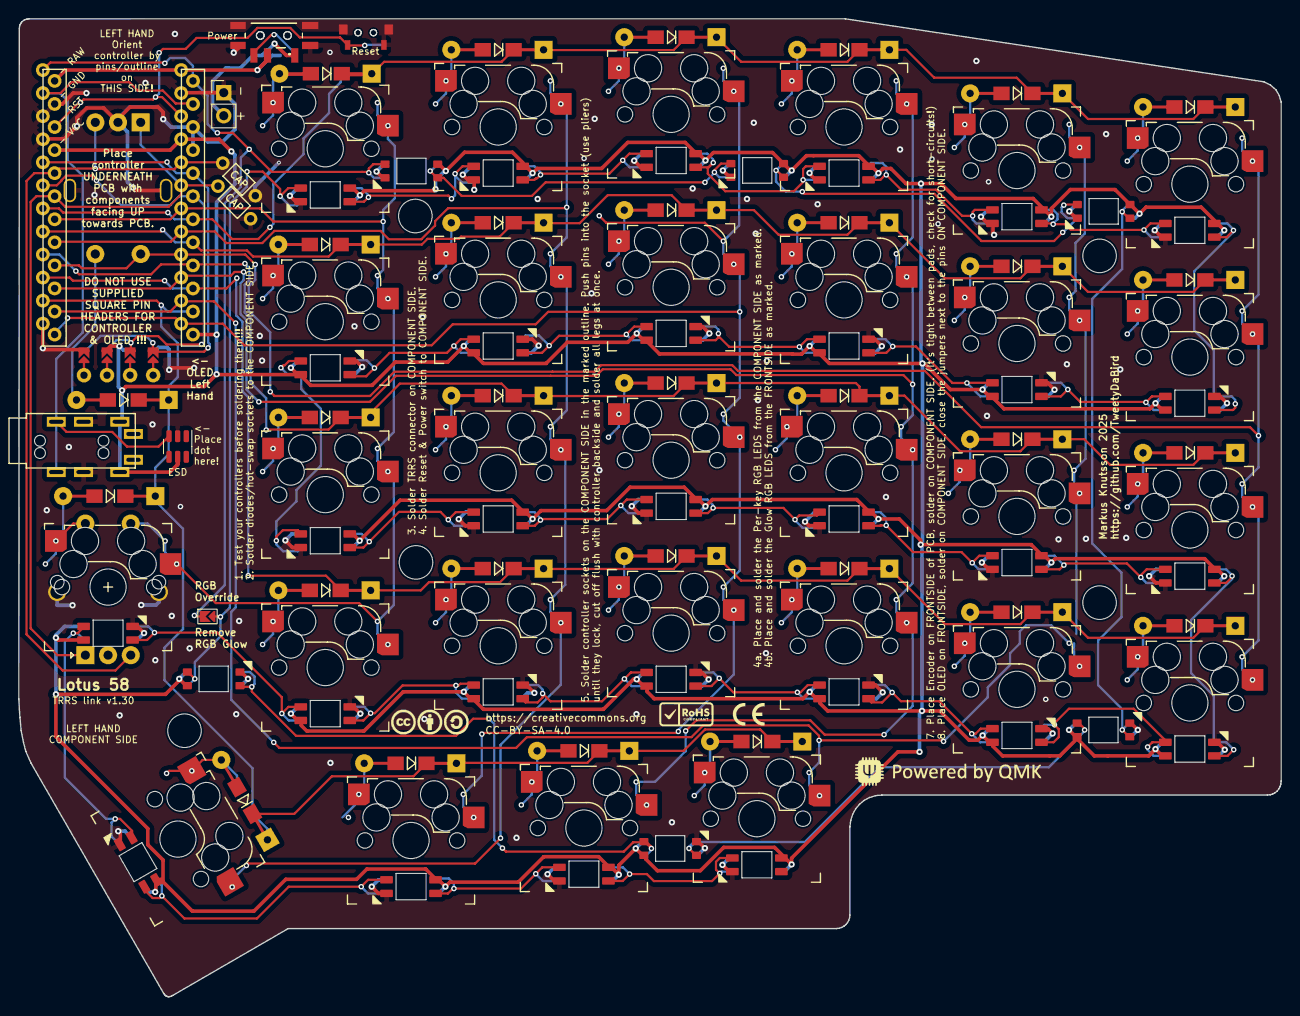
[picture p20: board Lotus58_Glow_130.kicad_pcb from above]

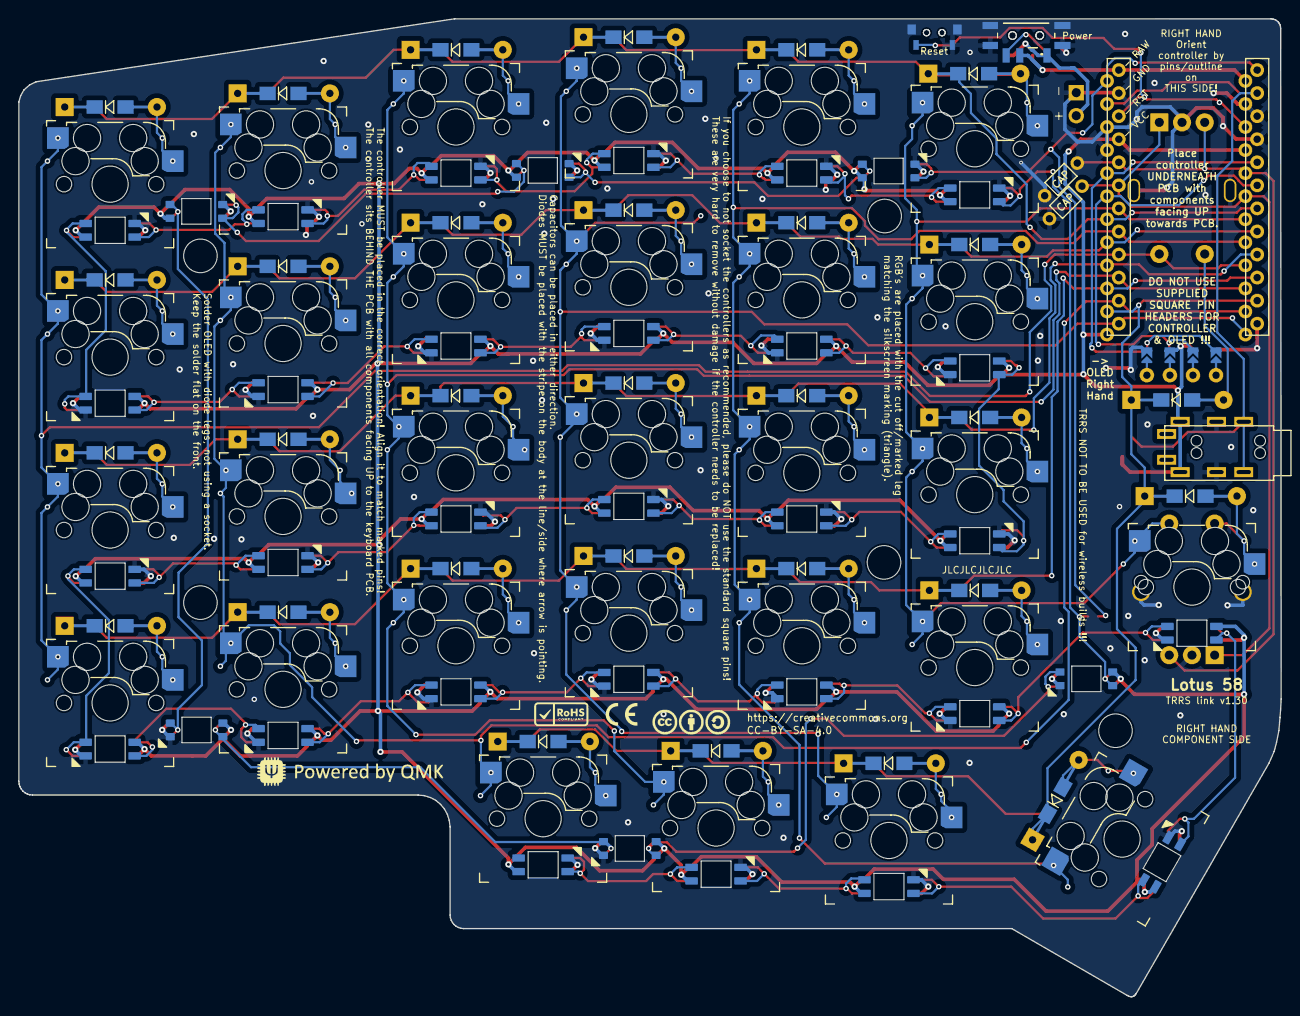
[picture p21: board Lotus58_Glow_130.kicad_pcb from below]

Board: 2 copper layers, 139.1 x 107.7 mm, 119 parts (71 on the bottom side), 86 nets.

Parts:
C1, C2: 50V/100nF axial; RESISTOR_Reversible
D1, D2, D3, D4, D5, D6, D7, D8, D9, D10, D11, D12, D13, D14, D15, D16, D17, D18, D19, D20, D21, D22, D23, D24, D25, D26, D27, D28, D29, D30: 1N4148/1N4148W; Diode_DO35_SOD123
J1: PJ-320A; MJ-4PP-9_alim
J2: Conn_01x02; PinHeader_1x02_P2.54mm_Vertical
JP5: FULL; Jumper_min_v2
LED1, LED2, LED3, LED4, LED5, LED6: SK6812MINI-E; MX_SK6812MINI-E_REVERSIBLE_special_v2
LED7, LED8, LED9, LED10, LED11, LED12, LED13, LED14, LED15, LED16, LED17, LED18, LED19, LED20, LED21, LED22, LED23, LED24, LED25, LED26, LED27, LED28, LED29, LED30, LED31, LED32, LED33, LED34, LED35: SK6803MINI-E; MX_SK6812MINI-E_REVERSIBLE
Logo1, Logo8: QMK_Logo; qmk logo
Logo2, Logo7: CC-BY-SA-4.0; CC_BY_SA_40_line
Logo5, Logo6: CE_Logo; CE
P1: OLED; SSD1306-0.91-OLED-4pin-128x32 doublesided
RES1, RES2: TS-A002; YTS-A002
S1, S2: MSK12C02
SW1, SW2, SW3, SW4, SW5, SW6, SW7, SW8, SW9, SW10, SW11, SW12, SW13, SW14, SW15, SW16, SW17, SW18, SW19, SW20, SW21, SW22, SW23, SW24, SW25, SW26, SW27, SW28, SW29: Kailh hotswap MX socket; SW_MX_HotSwap_Reversible
SW30: EC_11; RotaryEncoder_Alps_EC11E-Switch_Vertical_H20_special
SW31: EC_11; RotaryEncoder_Alps_EC11E-Switch_Special
TH1, TH2, TH3, TH4, TH5: HOLE; Spacer PCB hole
U1: Controller; ProMicro_Reversible_orig
U2: SRV05-4; SOT-23-6

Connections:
/Batt: J2.2, S1.NC, S2.NC
A: C2.2, SW30.A, SW31.A, U1.19 (A2/PF5)
Alt: D25.2 (A), SW25.2, SW31.S2
B: C1.2, SW30.B, SW31.B, U1.20 (A3/PF4)
Battery: S1.COM, S2.COM, U1.24 (RAW)
DATA: J1.R2, U1.2 (RX1/PD2), U2.3 (IO2)
GND: C1.1, C2.1, J1.R1, J2.1, LED1.3 (GND), LED2.3 (GND), LED3.3 (GND), LED4.3 (GND), LED5.3 (GND), LED6.3 (GND), LED7.3 (GND), LED8.3 (GND), LED9.3 (GND), LED10.3 (GND), LED11.3 (GND), LED12.3 (GND), LED13.3 (GND), LED14.3 (GND), LED15.3 (GND), LED16.3 (GND), LED17.3 (GND), LED18.3 (GND), LED19.3 (GND), LED20.3 (GND), LED21.3 (GND), LED22.3 (GND), LED23.3 (GND), LED24.3 (GND), LED25.3 (GND), LED26.3 (GND), LED27.3 (GND), LED28.3 (GND), LED29.3 (GND), LED30.3 (GND), LED31.3 (GND), LED32.3 (GND), LED33.3 (GND), LED34.3 (GND), LED35.3 (GND), P1.1 (GND), RES1.2, RES1.3, RES2.2, RES2.3, S1.MP (GND), S2.MP (GND), SW30.C, SW30.MP1 (GND), SW30.MP2 (GND), SW31.C, SW31.MP1 (GND), SW31.MP2 (GND), U1.3 (GND), U1.4 (GND), U1.23 (GND), U2.2 (VN)
LED: JP5.1, LED1.4 (DIN), U1.1 (TX0/PD3)
unnamed: D1.2 (A), SW1.2
unnamed: D2.2 (A), SW2.2
unnamed: D3.2 (A), SW3.2
unnamed: D4.2 (A), SW4.2
unnamed: D5.2 (A), SW5.2
unnamed: D6.2 (A), SW6.2
unnamed: D7.2 (A), SW7.2
unnamed: D8.2 (A), SW8.2
unnamed: D9.2 (A), SW9.2
unnamed: D10.2 (A), SW10.2
unnamed: D11.2 (A), SW11.2
unnamed: D12.2 (A), SW12.2
unnamed: D13.2 (A), SW13.2
unnamed: D14.2 (A), SW14.2
unnamed: D15.2 (A), SW15.2
unnamed: D16.2 (A), SW16.2
unnamed: D17.2 (A), SW17.2
unnamed: D18.2 (A), SW18.2
unnamed: D19.2 (A), SW19.2
unnamed: D20.2 (A), SW20.2
unnamed: D21.2 (A), SW21.2
unnamed: D22.2 (A), SW22.2
unnamed: D23.2 (A), SW23.2
unnamed: D24.2 (A), SW24.2
unnamed: D26.2 (A), SW26.2
unnamed: D27.2 (A), SW27.2
unnamed: D28.2 (A), SW28.2
unnamed: D29.2 (A), SW29.2
unnamed: D30.2 (A), SW30.S1
unnamed: LED1.2 (DOUT), LED2.4 (DIN)
unnamed: LED2.2 (DOUT), LED3.4 (DIN)
unnamed: LED3.2 (DOUT), LED4.4 (DIN)
unnamed: LED4.2 (DOUT), LED5.4 (DIN)
unnamed: LED5.2 (DOUT), LED6.4 (DIN)
unnamed: LED7.2 (DOUT), LED8.4 (DIN)
unnamed: LED8.2 (DOUT), LED9.4 (DIN)
unnamed: LED9.2 (DOUT), LED10.4 (DIN)
unnamed: LED10.2 (DOUT), LED11.4 (DIN)
unnamed: LED11.2 (DOUT), LED12.4 (DIN)
unnamed: LED12.2 (DOUT), LED18.4 (DIN)
unnamed: LED13.4 (DIN), LED14.2 (DOUT)
unnamed: LED13.2 (DOUT), LED19.4 (DIN)
unnamed: LED14.4 (DIN), LED15.2 (DOUT)
unnamed: LED15.4 (DIN), LED16.2 (DOUT)
unnamed: LED16.4 (DIN), LED17.2 (DOUT)
unnamed: LED17.4 (DIN), LED18.2 (DOUT)
unnamed: LED19.2 (DOUT), LED20.4 (DIN)
unnamed: LED20.2 (DOUT), LED21.4 (DIN)
unnamed: LED21.2 (DOUT), LED22.4 (DIN)
unnamed: LED22.2 (DOUT), LED23.4 (DIN)
unnamed: LED23.2 (DOUT), LED24.4 (DIN)
unnamed: LED24.2 (DOUT), LED30.4 (DIN)
unnamed: LED25.4 (DIN), LED26.2 (DOUT)
unnamed: LED25.2 (DOUT), LED31.4 (DIN)
unnamed: LED26.4 (DIN), LED27.2 (DOUT)
unnamed: LED27.4 (DIN), LED28.2 (DOUT)
unnamed: LED28.4 (DIN), LED29.2 (DOUT)
unnamed: LED29.4 (DIN), LED30.2 (DOUT)
unnamed: LED31.2 (DOUT), LED32.4 (DIN)
unnamed: LED32.2 (DOUT), LED33.4 (DIN)
unnamed: LED33.2 (DOUT), LED34.4 (DIN)
unnamed: LED34.2 (DOUT), LED35.4 (DIN)
RESET: RES1.1, RES2.1, U1.22 (RST)
RGB_LINK: JP5.2, LED6.2 (DOUT), LED7.4 (DIN)
SCL: P1.3 (SCL), U1.6 (3/PD0)
SDA: P1.4 (SDA), U1.5 (2/PD1)
VCC: J1.T, LED1.1 (VCC), LED2.1 (VCC), LED3.1 (VCC), LED4.1 (VCC), LED5.1 (VCC), LED6.1 (VCC), LED7.1 (VCC), LED8.1 (VCC), LED9.1 (VCC), LED10.1 (VCC), LED11.1 (VCC), LED12.1 (VCC), LED13.1 (VCC), LED14.1 (VCC), LED15.1 (VCC), LED16.1 (VCC), LED17.1 (VCC), LED18.1 (VCC), LED19.1 (VCC), LED20.1 (VCC), LED21.1 (VCC), LED22.1 (VCC), LED23.1 (VCC), LED24.1 (VCC), LED25.1 (VCC), LED26.1 (VCC), LED27.1 (VCC), LED28.1 (VCC), LED29.1 (VCC), LED30.1 (VCC), LED31.1 (VCC), LED32.1 (VCC), LED33.1 (VCC), LED34.1 (VCC), LED35.1 (VCC), P1.2 (VCC), U1.21 (VCC), U2.5 (VP)
col0: SW6.1, SW12.1, SW18.1, SW24.1, SW30.S2, U1.16 (15/PB1)
col1: SW5.1, SW11.1, SW17.1, SW23.1, SW29.1, U1.14 (16/PB2)
col2: SW4.1, SW10.1, SW16.1, SW22.1, SW28.1, U1.15 (14/PB3)
col3: SW3.1, SW9.1, SW15.1, SW21.1, SW27.1, U1.13 (10/PB6)
col4: SW2.1, SW8.1, SW14.1, SW20.1, SW26.1, U1.17 (A0/PF7)
col5: SW1.1, SW7.1, SW13.1, SW19.1, SW25.1, SW31.S1, U1.18 (A1/PF6)
row0: D1.1 (K), D2.1 (K), D3.1 (K), D4.1 (K), D5.1 (K), D6.1 (K), U1.7 (4/PD4)
row1: D7.1 (K), D8.1 (K), D9.1 (K), D10.1 (K), D11.1 (K), D12.1 (K), U1.8 (5/PC6)
row2: D13.1 (K), D14.1 (K), D15.1 (K), D16.1 (K), D17.1 (K), D18.1 (K), U1.9 (6/PD7)
row3: D19.1 (K), D20.1 (K), D21.1 (K), D22.1 (K), D23.1 (K), D24.1 (K), U1.10 (7/PE6)
row4: D25.1 (K), D26.1 (K), D27.1 (K), D28.1 (K), D29.1 (K), D30.1 (K), U1.11 (8/PB4)

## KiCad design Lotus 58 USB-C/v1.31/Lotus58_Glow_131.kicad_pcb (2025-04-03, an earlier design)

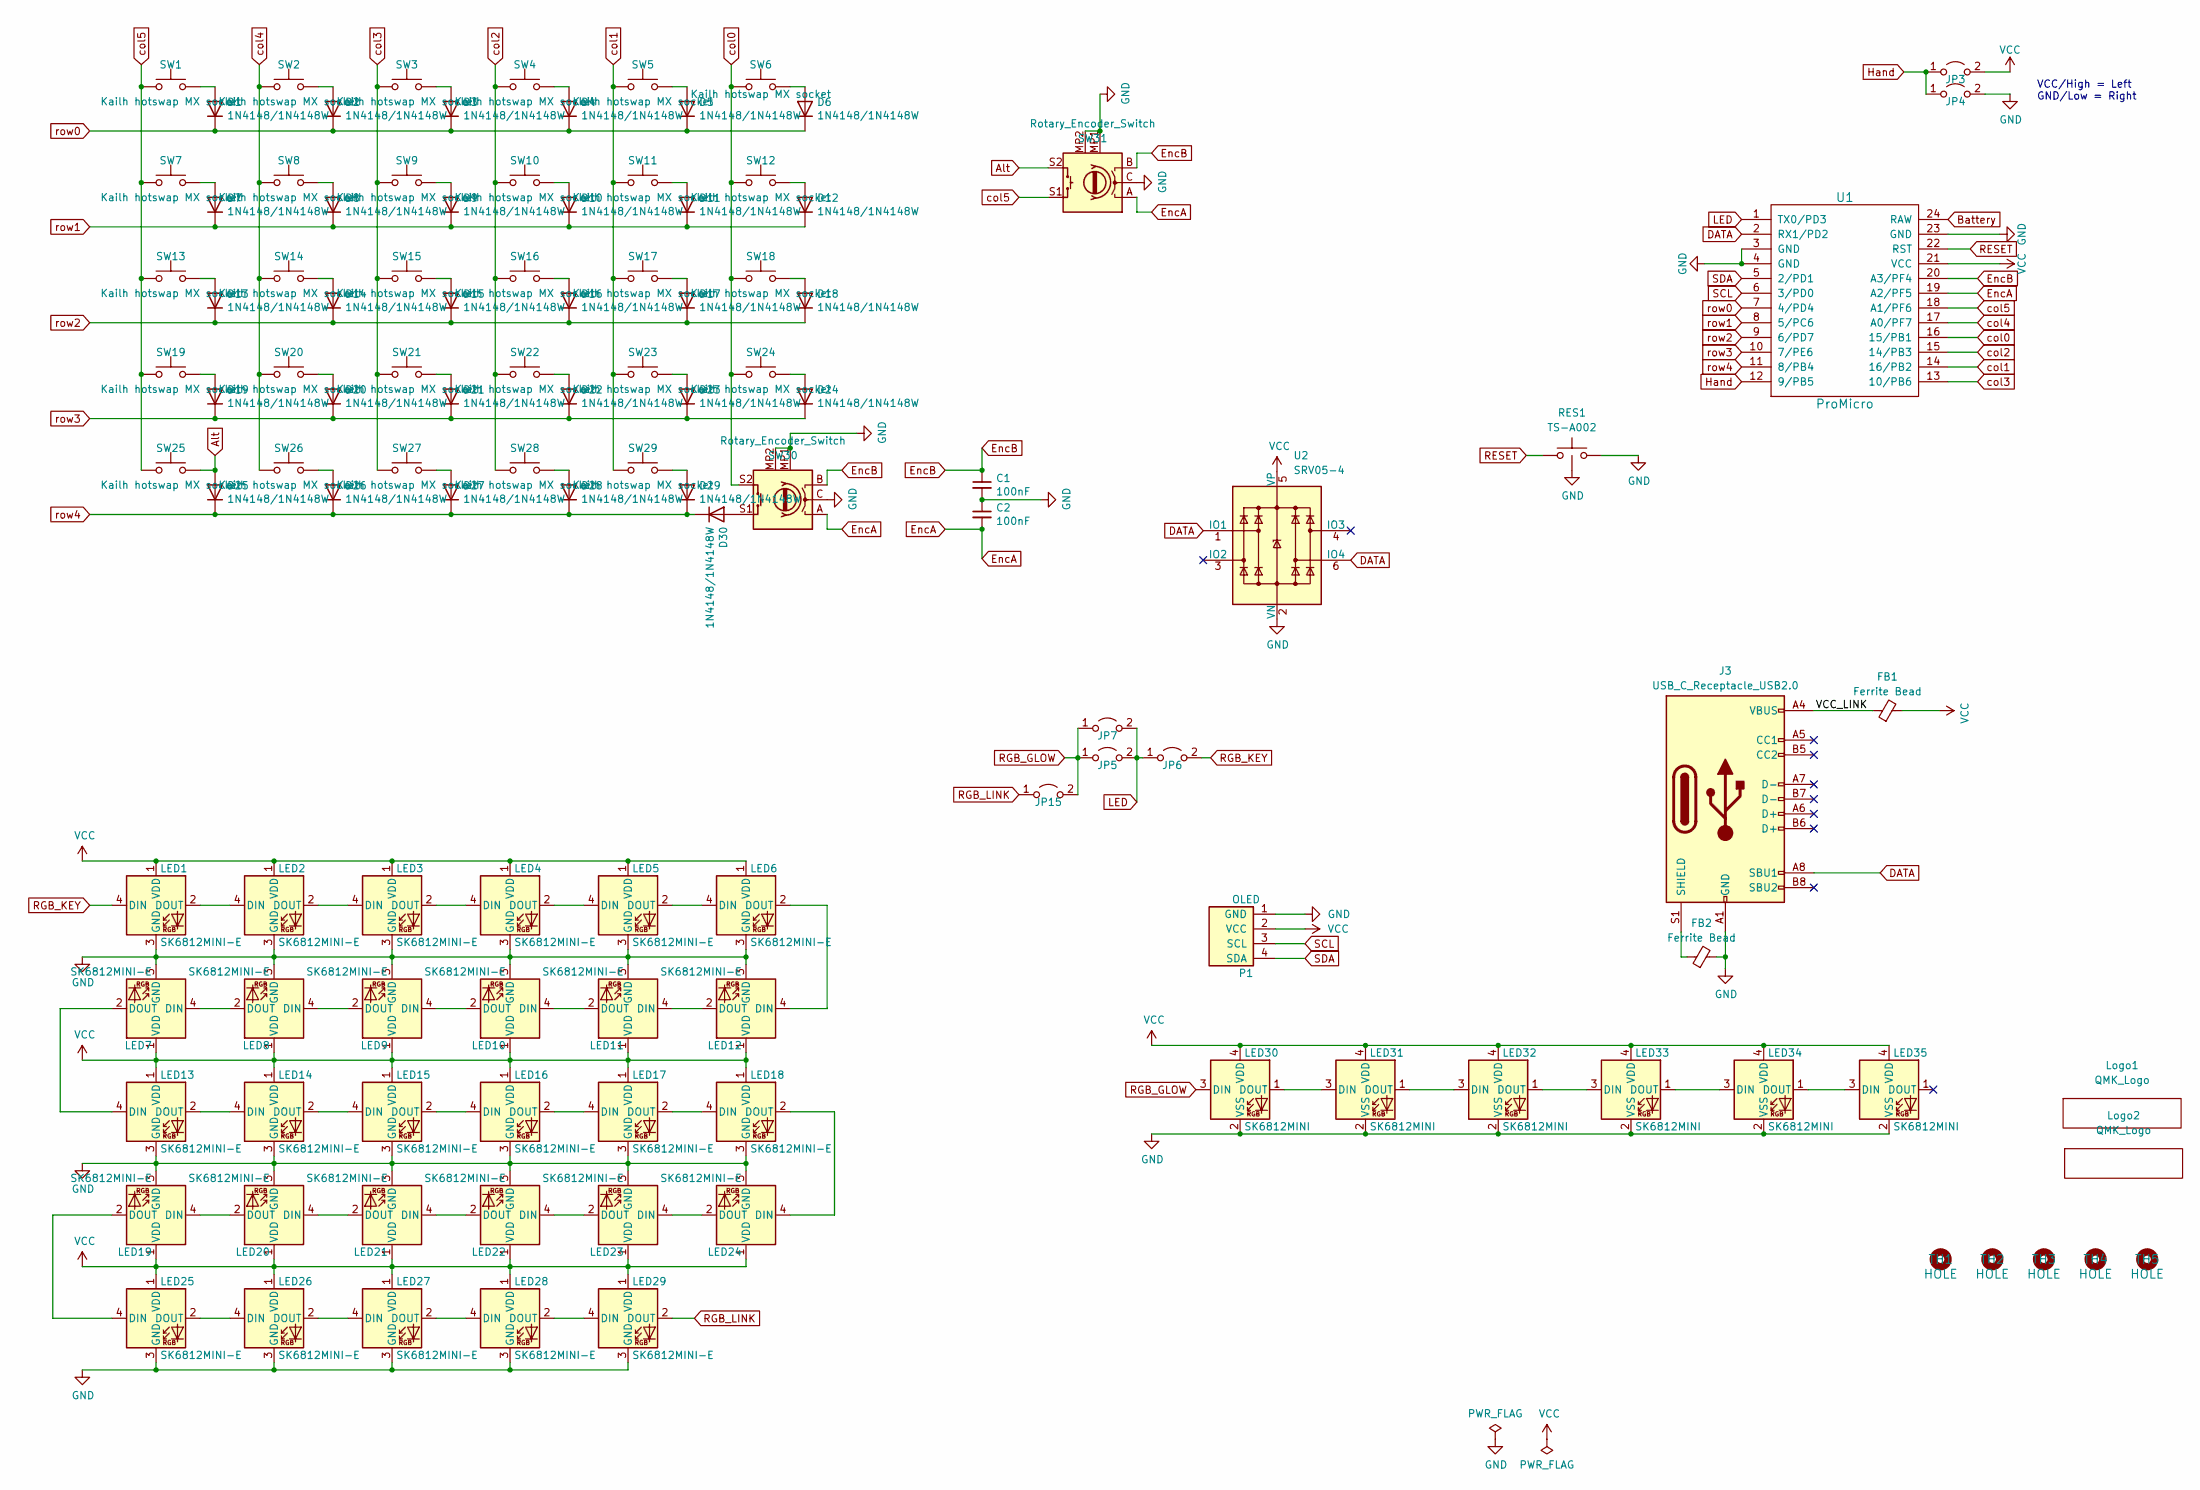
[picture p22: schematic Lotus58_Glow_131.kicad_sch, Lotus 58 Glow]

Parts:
C1, C2: 100nF; RESISTOR_Reversible
D1, D2, D3, D4, D5, D6, D7, D8, D9, D10, D11, D12, D13, D14, D15, D16, D17, D18, D19, D20, D21, D22, D23, D24, D25, D26, D27, D28, D29, D30: 1N4148/1N4148W; Diode_DO35_SOD123
FB1, FB2: Ferrite Bead; C_0603_1608Metric_Pad1.08x0.95mm_HandSolder; LCSC C882974
J3: USB_C_Receptacle_USB2.0; Molex-216990_GCT-USB45xx_HRO-TYPE-C-31-M-13x-PiMicro; LCSC C963373
JP3: LEFT; Jumper_Mini
JP4: RIGHT; Jumper_Mini
JP5, JP6, JP7, JP15: FULL; Jumper_Mini
LED1, LED2, LED3, LED4, LED5, LED6, LED7, LED8, LED9, LED10, LED11, LED12, LED13, LED14, LED15, LED16, LED17, LED18, LED19, LED20, LED21, LED22, LED23, LED24, LED25, LED26, LED27, LED28, LED29: SK6812MINI-E; MX_SK6812MINI-E_REVERSIBLE
LED30, LED31, LED32, LED33, LED34, LED35: SK6812MINI; LED_SK6812MINI_PLCC4_3.5x3.5mm_P1.75mmdouble
Logo1, Logo2: QMK_Logo; qmk logo
P1: OLED; SSD1306-0.91-OLED-4pin-128x32 doublesided
RES1: TS-A002; YTS-A002; LCSC C2888934
SW1, SW2, SW3, SW4, SW5, SW6, SW7, SW8, SW9, SW10, SW11, SW12, SW13, SW14, SW15, SW16, SW17, SW18, SW19, SW20, SW21, SW22, SW23, SW24, SW25, SW26, SW27, SW28, SW29: Kailh hotswap MX socket; SW_MX_HotSwap_Reversible
SW30: Rotary_Encoder_Switch; Encoder_Alps_EC11E_Small
SW31: Rotary_Encoder_Switch; Encoder_Alps_EC11E_Offset_pad
TH1, TH2, TH3, TH4, TH5: HOLE; Spacer PCB hole
U1: ProMicro; ProMicro_jumpers_V2
U2: SRV05-4; SOT-23-6; LCSC C558418

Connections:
/VCC_LINK: FB1.1, J3.A4 (VBUS), J3.A9 (VBUS), J3.B4 (VBUS), J3.B9 (VBUS)
Alt: D25.2 (A), SW25.1, SW31.S2
Battery: U1.24 (RAW)
DATA: J3.A8 (SBU1), U1.2 (RX1/PD2), U2.1 (IO1), U2.6 (IO4)
EncA: C2.2, SW30.A, SW31.A, U1.19 (A2/PF5)
EncB: C1.1, SW30.B, SW31.B, U1.20 (A3/PF4)
GND: C1.2, C2.1, FB2.2, J3.A1 (GND), J3.A12 (GND), J3.B1 (GND), J3.B12 (GND), JP4.2 (B), LED1.3 (GND), LED2.3 (GND), LED3.3 (GND), LED4.3 (GND), LED5.3 (GND), LED6.3 (GND), LED7.3 (GND), LED8.3 (GND), LED9.3 (GND), LED10.3 (GND), LED11.3 (GND), LED12.3 (GND), LED13.3 (GND), LED14.3 (GND), LED15.3 (GND), LED16.3 (GND), LED17.3 (GND), LED18.3 (GND), LED19.3 (GND), LED20.3 (GND), LED21.3 (GND), LED22.3 (GND), LED23.3 (GND), LED24.3 (GND), LED25.3 (GND), LED26.3 (GND), LED27.3 (GND), LED28.3 (GND), LED29.3 (GND), LED30.2 (VSS), LED31.2 (VSS), LED32.2 (VSS), LED33.2 (VSS), LED34.2 (VSS), LED35.2 (VSS), P1.1 (GND), RES1.2, RES1.3, SW30.C, SW30.MP1 (GND), SW30.MP2 (GND), SW31.C, SW31.MP1 (GND), SW31.MP2 (GND), U1.3 (GND), U1.4 (GND), U1.23 (GND), U2.2 (VN)
Hand: JP3.1 (A), JP4.1 (A), U1.12 (9/PB5)
LED: JP5.2 (B), JP6.1 (A), JP7.2 (B), U1.1 (TX0/PD3)
unnamed: D1.2 (A), SW1.1
unnamed: D2.2 (A), SW2.1
unnamed: D3.2 (A), SW3.1
unnamed: D4.2 (A), SW4.1
unnamed: D5.2 (A), SW5.1
unnamed: D6.2 (A), SW6.1
unnamed: D7.2 (A), SW7.1
unnamed: D8.2 (A), SW8.1
unnamed: D9.2 (A), SW9.1
unnamed: D10.2 (A), SW10.1
unnamed: D11.2 (A), SW11.1
unnamed: D12.2 (A), SW12.1
unnamed: D13.2 (A), SW13.1
unnamed: D14.2 (A), SW14.1
unnamed: D15.2 (A), SW15.1
unnamed: D16.2 (A), SW16.1
unnamed: D17.2 (A), SW17.1
unnamed: D18.2 (A), SW18.1
unnamed: D19.2 (A), SW19.1
unnamed: D20.2 (A), SW20.1
unnamed: D21.2 (A), SW21.1
unnamed: D22.2 (A), SW22.1
unnamed: D23.2 (A), SW23.1
unnamed: D24.2 (A), SW24.1
unnamed: D26.2 (A), SW26.1
unnamed: D27.2 (A), SW27.1
unnamed: D28.2 (A), SW28.1
unnamed: D29.2 (A), SW29.1
unnamed: D30.2 (A), SW30.S1
unnamed: FB2.1, J3.S1 (SHIELD)
unnamed: LED1.2 (DOUT), LED2.4 (DIN)
unnamed: LED2.2 (DOUT), LED3.4 (DIN)
unnamed: LED3.2 (DOUT), LED4.4 (DIN)
unnamed: LED4.2 (DOUT), LED5.4 (DIN)
unnamed: LED5.2 (DOUT), LED6.4 (DIN)
unnamed: LED7.4 (DIN), LED8.2 (DOUT)
unnamed: LED8.4 (DIN), LED9.2 (DOUT)
unnamed: LED10.4 (DIN), LED11.2 (DOUT)
unnamed: LED9.4 (DIN), LED10.2 (DOUT)
unnamed: LED11.4 (DIN), LED12.2 (DOUT)
unnamed: LED6.2 (DOUT), LED12.4 (DIN)
unnamed: LED7.2 (DOUT), LED13.4 (DIN)
unnamed: LED13.2 (DOUT), LED14.4 (DIN)
unnamed: LED14.2 (DOUT), LED15.4 (DIN)
unnamed: LED15.2 (DOUT), LED16.4 (DIN)
unnamed: LED16.2 (DOUT), LED17.4 (DIN)
unnamed: LED17.2 (DOUT), LED18.4 (DIN)
unnamed: LED18.2 (DOUT), LED24.4 (DIN)
unnamed: LED19.4 (DIN), LED20.2 (DOUT)
unnamed: LED19.2 (DOUT), LED25.4 (DIN)
unnamed: LED20.4 (DIN), LED21.2 (DOUT)
unnamed: LED21.4 (DIN), LED22.2 (DOUT)
unnamed: LED22.4 (DIN), LED23.2 (DOUT)
unnamed: LED23.4 (DIN), LED24.2 (DOUT)
unnamed: LED25.2 (DOUT), LED26.4 (DIN)
unnamed: LED26.2 (DOUT), LED27.4 (DIN)
unnamed: LED27.2 (DOUT), LED28.4 (DIN)
unnamed: LED28.2 (DOUT), LED29.4 (DIN)
unnamed: LED30.1 (DOUT), LED31.3 (DIN)
unnamed: LED31.1 (DOUT), LED32.3 (DIN)
unnamed: LED32.1 (DOUT), LED33.3 (DIN)
unnamed: LED33.1 (DOUT), LED34.3 (DIN)
unnamed: LED34.1 (DOUT), LED35.3 (DIN)
RESET: RES1.1, U1.22 (RST)
RGB_GLOW: JP5.1 (A), JP7.1 (A), JP15.2 (B), LED30.3 (DIN)
RGB_KEY: JP6.2 (B), LED1.4 (DIN)
RGB_LINK: JP15.1 (A), LED29.2 (DOUT)
SCL: P1.3 (SCL), U1.6 (3/PD0)
SDA: P1.4 (SDA), U1.5 (2/PD1)
VCC: FB1.2, JP3.2 (B), LED1.1 (VDD), LED2.1 (VDD), LED3.1 (VDD), LED4.1 (VDD), LED5.1 (VDD), LED6.1 (VDD), LED7.1 (VDD), LED8.1 (VDD), LED9.1 (VDD), LED10.1 (VDD), LED11.1 (VDD), LED12.1 (VDD), LED13.1 (VDD), LED14.1 (VDD), LED15.1 (VDD), LED16.1 (VDD), LED17.1 (VDD), LED18.1 (VDD), LED19.1 (VDD), LED20.1 (VDD), LED21.1 (VDD), LED22.1 (VDD), LED23.1 (VDD), LED24.1 (VDD), LED25.1 (VDD), LED26.1 (VDD), LED27.1 (VDD), LED28.1 (VDD), LED29.1 (VDD), LED30.4 (VDD), LED31.4 (VDD), LED32.4 (VDD), LED33.4 (VDD), LED34.4 (VDD), LED35.4 (VDD), P1.2 (VCC), U1.21 (VCC), U2.5 (VP)
col0: SW6.2, SW12.2, SW18.2, SW24.2, SW30.S2, U1.16 (15/PB1)
col1: SW5.2, SW11.2, SW17.2, SW23.2, SW29.2, U1.14 (16/PB2)
col2: SW4.2, SW10.2, SW16.2, SW22.2, SW28.2, U1.15 (14/PB3)
col3: SW3.2, SW9.2, SW15.2, SW21.2, SW27.2, U1.13 (10/PB6)
col4: SW2.2, SW8.2, SW14.2, SW20.2, SW26.2, U1.17 (A0/PF7)
col5: SW1.2, SW7.2, SW13.2, SW19.2, SW25.2, SW31.S1, U1.18 (A1/PF6)
row0: D1.1 (K), D2.1 (K), D3.1 (K), D4.1 (K), D5.1 (K), D6.1 (K), U1.7 (4/PD4)
row1: D7.1 (K), D8.1 (K), D9.1 (K), D10.1 (K), D11.1 (K), D12.1 (K), U1.8 (5/PC6)
row2: D13.1 (K), D14.1 (K), D15.1 (K), D16.1 (K), D17.1 (K), D18.1 (K), U1.9 (6/PD7)
row3: D19.1 (K), D20.1 (K), D21.1 (K), D22.1 (K), D23.1 (K), D24.1 (K), U1.10 (7/PE6)
row4: D25.1 (K), D26.1 (K), D27.1 (K), D28.1 (K), D29.1 (K), D30.1 (K), U1.11 (8/PB4)

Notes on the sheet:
VCC/High = Left GND/Low = Right

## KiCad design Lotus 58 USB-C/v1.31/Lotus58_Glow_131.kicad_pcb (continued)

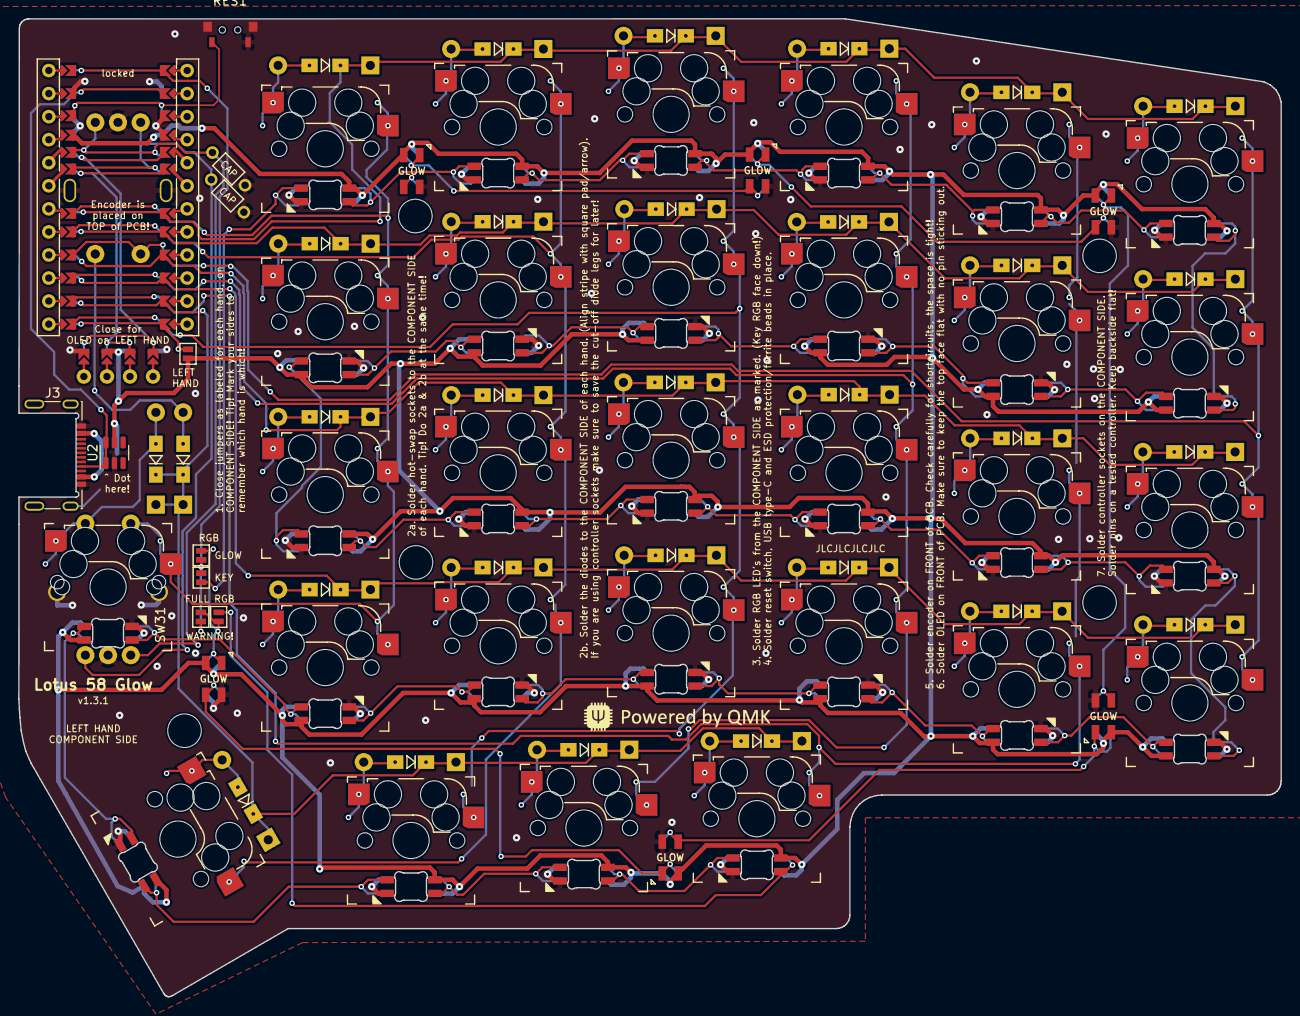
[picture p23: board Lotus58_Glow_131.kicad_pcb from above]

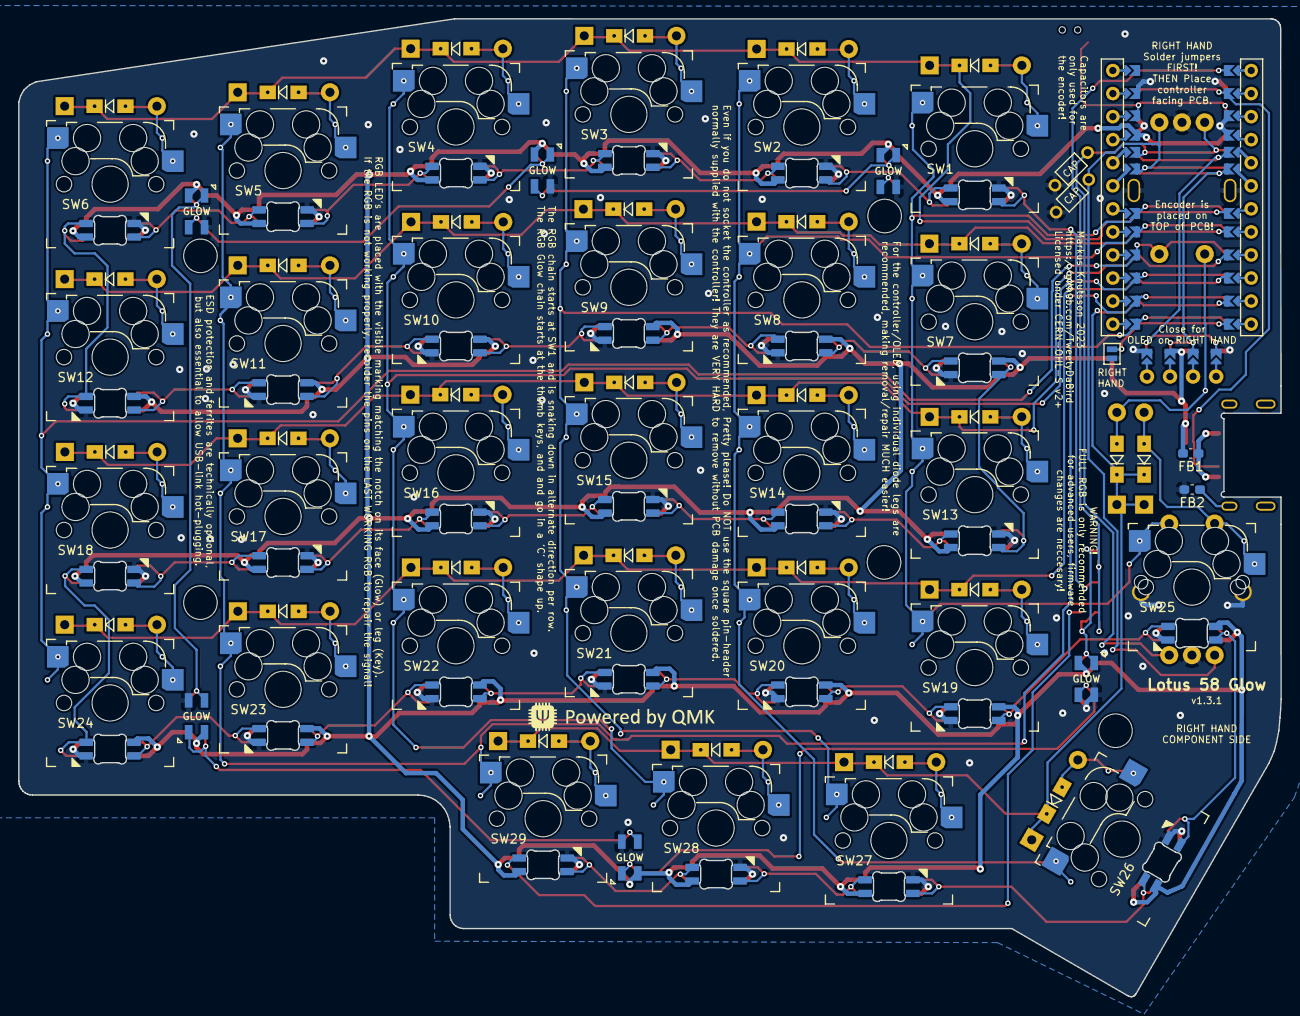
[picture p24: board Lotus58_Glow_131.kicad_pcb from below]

Board: 2 copper layers, 139.1 x 107.7 mm, 118 parts (36 on the bottom side), 89 nets.

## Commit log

2023-12-27 Initial commit v1.28
    [Lotus58_Glow_128.kicad_pcb, Lotus58_Glow_128.kicad_sch]
2024-01-11 Move files
    [FR4_Bottom_Plate.step, FR4_Bottom_Plate_TENT.step, FR4_Top_Plate_BLANK.step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]
2024-01-11 House cleaning
    [Lotus58_Glow_125.kicad_sch]
2024-01-11 v1.41
    Changed silkscreeen
    [Lotus58_Glow_141.kicad_pcb]
2024-01-11 Tweaked 1.41
    [Lotus58_Glow_128.kicad_pcb, Lotus58_Glow_141.kicad_pcb]
2024-04-07 Renamed folders
    Making place for new versions, housekeeping of files
    [FR4_Bottom_Plate.kicad_pcb, FR4_Bottom_Plate.step, FR4_Bottom_Plate_TENT.kicad_pcb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]
2024-04-14 USB-C v1.42
    mirror to allow PCBA
    [Lotus58_Glow_142.kicad_pcb, Lotus58_Glow_142.kicad_sch]
2024-05-16 Lotus 58 Classic
    Intial design v1.00
    [Lotus58_Classic.kicad_pcb, Lotus58_Classic.kicad_sch, Lotus58_Glow_111.kicad_pcb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]
2024-05-19 Lotus 58 Classic
    Tweaks
    [Lotus58_Classic.kicad_pcb, Lotus58_Classic.kicad_sch]
2024-05-19 Lotus 58 EZ
    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
    [Lotus58_EZ_100.kicad_pcb, Lotus58_EZ_100.kicad_sch]
2025-02-07 Add - PDF versions of schematics 1.24 / 1.28 / 1.30
2025-04-03 Lotus 58 - USB Link v1.50
    [Lotus58_Glow_150.kicad_pcb, Lotus58_Glow_150.kicad_sch]
2025-04-03 Lotus 58 - Plate
    added nice!view
    [FR4_Top_Plate_OLED.kicad_pcb, FR4_Top_Plate_n!v.kicad_pcb]
2025-04-03 Lotus 58 - USB Link v1.51
    adjusted RGB Gl
    ow, Silkscreen
    [Lotus58_Glow_151.kicad_pcb, Lotus58_Glow_151.kicad_sch]
2025-04-03 Lotus 58 - TRRS Link v1.30
    [Lotus58_Glow_130.kicad_pcb, Lotus58_Glow_130.kicad_sch]
2025-04-03 test bom
2025-04-03 Revert "test bom"
    This reverts commit 6c63932caec8bfd1a810df5035c629821b470d4d.
2025-04-03 Corrected iBom
    [Lotus58_Glow_151.kicad_pcb]
2025-04-03 Corrected iBom
    USB v1.51
    [Bottom.xlsx, Lotus58_Glow_151.kicad_sch, Top.xlsx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]
2025-04-03 Lotus 58 - TRRS Link v1.30
    release ready
    [Lotus58_Glow_130.kicad_pcb, Lotus58_Glow_130.kicad_sch, Lotus58_Glow_151.kicad_pcb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]

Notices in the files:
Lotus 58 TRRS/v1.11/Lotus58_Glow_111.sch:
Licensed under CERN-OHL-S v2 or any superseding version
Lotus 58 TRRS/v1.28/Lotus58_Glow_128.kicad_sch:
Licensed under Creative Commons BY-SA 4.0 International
